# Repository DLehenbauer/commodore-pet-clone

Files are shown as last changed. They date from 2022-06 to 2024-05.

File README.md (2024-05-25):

## PET Clone

Open hardware clone of the Commodore CBM/PET using modern parts.
Some assembly required.  :-)

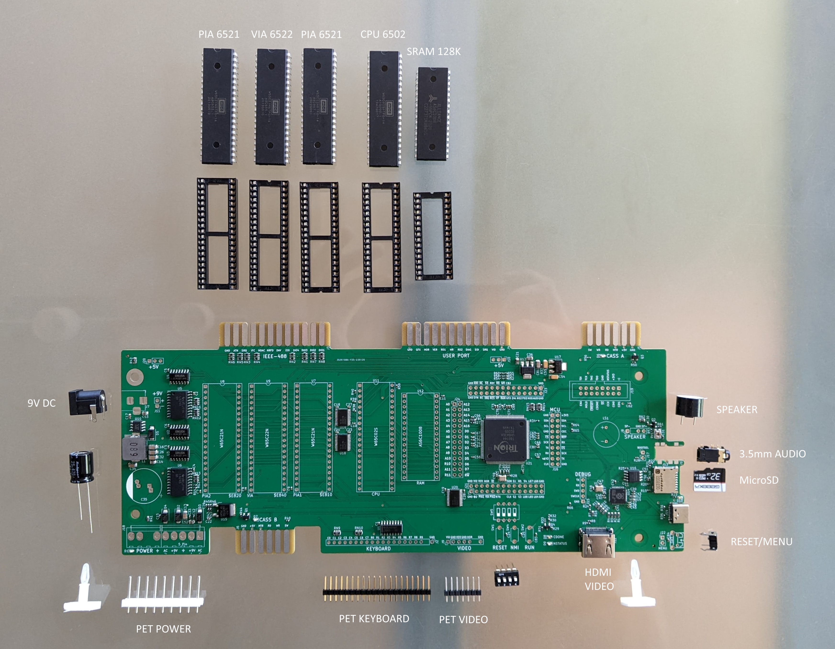
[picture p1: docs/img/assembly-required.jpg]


## Status

Working prototype.  PCB and SMT manufacturing files are [here](https://github.com/DLehenbauer/commodore-pet-clone/tree/main/hw/Mainboard/production).

## About

This open hardware CBM/PET clone can be used in two ways:

1. By itself with an HDMI display and USB keyboard
2. As a mainboard replacement to repair/enhance a vintage CBM/PET

You can also do both at once, as shown in the image below:

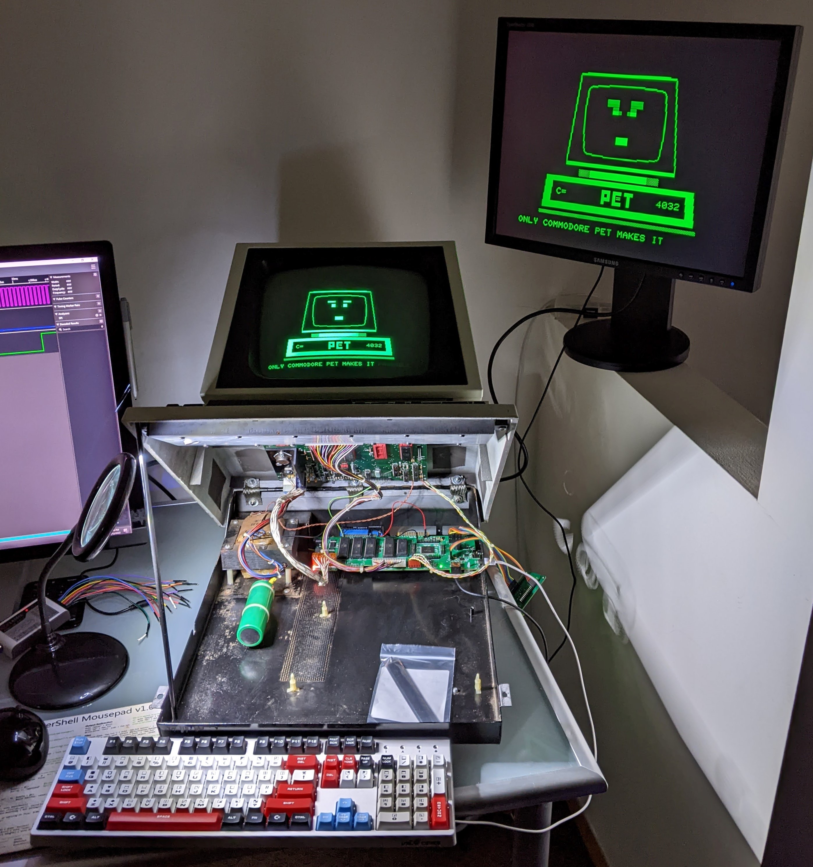
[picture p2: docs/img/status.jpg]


## Design

The following block diagram provides an overview of the system architecture:



Here are the highlights:

* CPU and I/O are similar to the original Commodore design, using the 6502, PIA, and VIA.
* Main RAM, Display RAM and ROM are combined on a single 128K SRAM.
  * On POR the MCU initializes $9000-FFFF with the user's selected ROM set
  * After initialization, $9000-FFFF is write protected.
* Timing, address decoding, and native PET video are consolidated on a small FPGA.
* The MCU reads display RAM and mirrors the PET video to HDMI (via bit-banged DVI)
* The MCU also reports USB keyboard input to the FPGA
  * The FPGA intercepts reads from $E812 to inject USB key input as-needed
  * When no USB keys are pressed, the read passes through to PIA1.

## Contributing

Collaborators warmly appreciated (see [Issues](https://github.com/DLehenbauer/commodore-pet-clone/issues)).

## License

This project is public domain under the CC0-1.0 license, exempting portions incorporated
from other open source projects as noted [here](NOTICE.md) and in the source code.



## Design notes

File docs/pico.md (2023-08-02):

# Pico Debugging

Used ExpressIf directions
[Outdated setup for WSL2](https://github.com/robotdad/piconotes)

Setup:

* Flash Pico with the [Picoprobe UF2 file](https://www.raspberrypi.com/documentation/microcontrollers/raspberry-pi-pico.html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).

## Share Picoprobe with WSL

```sh
usbipd wsl attach --hardware-id 2e8a:0004
```

## Listen to UART

```sh
minicom -b 115200 -o -D /dev/ttyACM0
```

## Specs

* [Device Class Definition for Human Interface Devices (HID)](https://www.usb.org/sites/default/files/hid1_11.pdf)
* [HID Usage Tables](https://usb.org/sites/default/files/hut1_3_0.pdf)
* [Pinout](https://pico.pinout.xyz/)

## CMD

7 | 6 | 5 | 4 | 3 | 2 | 1 | 0
-|-|-|-|-|-|-|-
 LEN[2] | LEN[1] | LEN[0] | x | x | x | RW_B | A16

CMD        |          binary             |      hex
-----------|-----------------------------|-----------------
READ_AT    | { 7'b011_xxx_1, addr[16] }  |
READ_NEXT  | { 8'b001_xxx_1_x            |
WRITE_AT   | { 7'b100_xxx_0, addr[16] }  |

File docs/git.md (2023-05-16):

# Git

## Fix broken submodule

1. Remove from .git/config
2. Remove from .gitmodules

```sh
rm -rf fw/external/no-OS-FatFS-SD-SPI-RPi-Pico
git rm --cached fw/external/no-OS-FatFS-SD-SPI-RPi-Pico
rm -rf .git/modules/fw/external/no-OS-FatFS-SD-SPI-RPi-Pico
```

Alternate:
```sh
git submodule deinit -f ./fw/external/no-OS-FatFS-SD-SPI-RPi-Pico
```

## Setup submodule at tag

```sh
pushd fw/external
git submodule add https://github.com/carlk3/no-OS-FatFS-SD-SPI-RPi-Pico.git
pushd no-OS-FatFS-SD-SPI-RPi-Pico
git fetch --tags
git checkout tags/v1.0.8
popd
git add no-OS-FatFS-SD-SPI-RPi-Pico
git commit -m "Move 'no-OS-FatFS-SD-SPI-RPi-Pico' to tags/v1.0.8"
popd
```

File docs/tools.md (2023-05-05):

# Tools

## PCB Design

* [KiCad](https://www.kicad.org/)
  * [JLC2KiCadLib](https://github.com/TousstNicolas/JLC2KiCad_lib)
  * [KiCAD JLCPCB tools](https://github.com/Bouni/kicad-jlcpcb-tools)
  * [Fabrication Toolkit](https://github.com/bennymeg/JLC-Plugin-for-KiCad)
* [Freerouting](https://github.com/freerouting/freerouting/releases)
  * `winget install -e --id EclipseAdoptium.Temurin.17.JRE`
* [LTSpice](https://www.analog.com/en/design-center/design-tools-and-calculators/ltspice-simulator.html)
  * [Parts](https://www.diyaudio.com/community/threads/a-large-free-ltspice-model-library.360086/)
* Online calculators
  * [VIA Size Calculator](https://j.mp/via-calc)
  * [Resistor Calculator](https://circuitdigest.com/calculators/lm317-resistor-voltage-calculator)
  * [LM317 Calculator](https://circuitdigest.com/calculators/lm317-resistor-voltage-calculator)
  * [Switch Debounce Calculator](https://clisystems.com/tool_debounce.php)
  * [Trace Width Calculator](https://www.digikey.com/en/resources/conversion-calculators/conversion-calculator-pcb-trace-width)
  * [Trace Impedance Calculator](https://www.eeweb.com/tools/edge-coupled-microstrip-impedance/)
* [JLCPCB Capabilities](https://jlcpcb.com/capabilities/Capabilities)
* [JLCPCB Parts Search](https://yaqwsx.github.io/jlcparts/#/)

Property            | Value
--------------------|--------------------------
Thickness           | 1.6 mm
Dielectric constant | 4.5 (double-sided PCB)
Outer copper layer  | 1 oz/ft^2 (35 um)

## FPGA & Verilog

* [Quartus II Web Edition 13.0 SP1](https://fpgasoftware.intel.com/13.0sp1/?edition=web)
* [Icarus Verilog & GTKWave](http://bleyer.org/icarus/)
* [vhd2vl](https://github.com/ldoolitt/vhd2vl)

## Logic Analyzer

* [PulseView](https://www.sigrok.org/wiki/Downloads) for [HiLetgo 8Ch Logic Analyzer](https://www.amazon.com/dp/B077LSG5P2)
  * Install WinUSB driver with [ZaDig](https://zadig.akeo.ie/) for device 0925 3881
* [KingstVIS](http://www.qdkingst.com/en/download) for [LA1010 16Ch Logic Analyzer](https://www.amazon.com/dp/B07D21GG6J)

## Drawing

* [Diagrams.net](https://app.diagrams.net/)
* [WaveDrom](https://wavedrom.com/editor.html)

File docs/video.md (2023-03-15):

# Video

## Non-CRTC Timing

Measurements from a 2001-32N (1979):

Signal | Frequency  | Source
-------|------------|----------
Crystal| 16.007 MHz | I1 pin 1
CPU    | 1.0009 MHz | 6502 pin 37
HSync  | 15.63 KHz  | Video pin 5 (consistent with 16.007 MHz / 1024 = 15.632 KHz)
VSync  | 60.12 Hz   | Video pin 3 (consistent with 15.632 KHz / 260 lines = ~60.122 Hz)

Closest CRTC settings:

Register | Value | Description
---------|-------|-----------------------------------------------
 R0      |   63  | H_TOTAL = 8 MHz pixel clock / 8 pixel char / (64 chars - 1) = 15.625 KHz
 R1      |   40  | H_DISPLAYED = 40 columns
 R2      |   48  | H_SYNC_POS
 R3[3:0] |    1  | H_SYNC_WIDTH = 1
 R3[7:4] |    5  | V_SYNC_WIDTH = 5
 R4      |   32  | V_TOTAL = 15.625 KHz / ((33 rows - 1) * 8 lines per row) = 61.04 Hz
 R5      |    5  | V_LINE_ADJUST = 15.625 KHz / (33 rows * 8 lines per row + 5 lines) = 60.10 Hz
 R6      |   25  | V_DISPLAYED = 25 rows
 R7      |   28  | V_SYNC_POS
 R9      |    7  | SCAN_LINE = 8 pixel character height (-1)

## CRTC Timing

Measurements from 8032 power on:

Signal | Frequency | Duty       | Source
-------|-----------|------------|-----------
HSync  | 20 KHz    | 70-70.126% | Video connector
VSync  | 60.062 Hz | 95.195%    | Video connector

## CRTC Bugs:

Noted problems in my current CRTC implementation:
* Bug in vertical timing: (61 Hz instead of 60 Hz)
* V. Sync width currently fixed at 16 scanlines (per original Motorola chips)

## Tools

* [VGA Timing Calculator](https://www.epanorama.net/faq/vga2rgb/calc.html)
* [Pixel Clock Calculator](https://www.monitortests.com/pixelclock.php)

## Reference

* VGA
  * [VGA Timings](http://martin.hinner.info/vga/timing.html)
  * [TinyVGA Timings](http://www.tinyvga.com/vga-timing)
* DVI
  * [CEA-861-D](https://ia903002.us.archive.org/1/items/CEA-861-D/CEA-861-D.pdf)
* NTSC / PAL
  * [Timing Characteristics](http://www.kolumbus.fi/pami1/video/pal_ntsc.html)
* CRTC
  * [Operation](http://www.6502.org/users/andre/hwinfo/crtc/crtc.html)
  * [Internals](http://www.6502.org/users/andre/hwinfo/crtc/internals/index.html)
  * [Wikipedia](https://en.wikipedia.org/wiki/Motorola_6845)
  * [Register Values](https://github.com/sjgray/cbm-edit-rom/blob/master/docs/CRTC%20Registers.txt)
  * [Reverse Engineering](https://stardot.org.uk/forums/viewtopic.php?t=22008)
  * Datasheet
    * [Rockwell R6545](http://archive.6502.org/datasheets/rockwell_r6545-1_crtc.pdf)
    * [Motorolla MC6845](http://m.www.datasheets.pl/elementy_czynne/IC/MC6845.pdf)
    * [C6845 CRT Controller IP](https://colorcomputerarchive.com/repo/Documents/Datasheets/SY6845E-C6845%20CRT%20Controller%20(CAST).pdf)

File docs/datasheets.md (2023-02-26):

# Datasheets

## 6502 CPU

* [Western Digital W65C02S](https://www.westerndesigncenter.com/wdc/documentation/w65c02s.pdf)

## 6520/6521 PIA

* [Western Digital W65C21](https://www.westerndesigncenter.com/wdc/documentation/w65c21.pdf)
* [Rockwell R6520](http://archive.6502.org/datasheets/rockwell_r6520_pia.pdf)

## 6522 VIA

* [Western Digital W65C22](https://www.westerndesigncenter.com/wdc/documentation/w65c22.pdf)

## 6545 CRTC

* [Rockwell R6545](http://archive.6502.org/datasheets/rockwell_r6545-1_crtc.pdf)

## SRAM

* [AS6C1008-55PCN](https://www.alliancememory.com/wp-content/uploads/pdf/AS6C1008feb2007.pdf)
* [IS61WV1288EEBLL](https://www.issi.com/WW/pdf/61-64WV1288EEBLL.pdf)

## MCU

* [RP2040](https://datasheets.raspberrypi.com/rp2040/rp2040-datasheet.pdf)
* [ARM PrimeCell Synchronous Serial Port (PL022)](https://developer.arm.com/documentation/ddi0194/h/introduction/about-the-arm-primecell-ssp--pl022-)

## Other

* [MC3446](http://pdf.datasheetcatalog.com/datasheets/400/501349_DS.pdf) Original IEEE-488 Bus Transceiver
* [SN74LVC4245A](https://www.ti.com/lit/ds/symlink/sn74lvc4245a.pdf) Octal Bus Transceiver and 3.3-V to 5-V Shifter
* [Card Edge Connector](https://files.edac.net/edac/content/305/305-024-500-501%20-%20EDAC%20Card%20Edge%20Connector.PDF)

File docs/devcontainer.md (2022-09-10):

[Picoprobe UF2 binary download](https://datasheets.raspberrypi.com/soft/picoprobe.uf2)

[Hints from ExpressIf Docs](https://github.com/espressif/vscode-esp-idf-extension/blob/HEAD/docs/tutorial/using-docker-container.md)

Install 'libusb-win32' driver for "Picoprobe (Interface 2)" using [Zadig](http://zadig.akeo.ie).

Install [usbipd](https://github.com/dorssel/usbipd-win/releases) on Windows

Install usbipd in WSL:
```
sudo apt update && \
    apt install linux-tools-5.4.0-77-generic hwdata && \
    update-alternatives --install /usr/local/bin/usbip usbip /usr/lib/linux-tools/5.4.0-77-generic/usbip 20
```

From PowerShell, list devices on Windows:

```
usbipd list wsl
```

Bind 'Picoprobe':

```
usbipd bind --busid 4-2
usbipd wsl attach --busid 4-2
```

Verify attachment from WSL and from container:
```
dmesg | tail
```

Verify that you can connect to the urt with minicom:
```
sudo minicom -D /dev/ttyACM0 -b 115200
```
(If not, you probably forgot to expose the device in the container with '--device=/dev/ttyACM0')

Test that OpenOCD can connect with 'sudo':
```
sudo openocd -f interface/picoprobe.cfg -f target/rp2040.cfg -s tcl
```
(If not, you probably forgot to start the container with --privileged)

TODO: Someday figure out how to connect to Picoprobe as a non-root user:
https://elinux.org/Accessing_Devices_without_Sudo

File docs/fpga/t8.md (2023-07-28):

# T8Q144

## Programming

### Install USB Driver

#### Windows

* Connect board to USB
* Run [Zadig](https://zadig.akeo.ie/) 2.7 or later
* Choose Options > List All Devices
* Select 'Dual RS232-HS'
* Select 'libusb-win32' driver
* Click 'Replace Driver'
* Repeat for 'USB Serial Converter'

## Documentation

Links to frequently referenced [Trion documentation](https://www.efinixinc.com/support/docs.php?p=t) (must [login](https://www.efinixinc.com/support/login.php) to access).

### Design

* [T8 Data Sheet](https://www.efinixinc.com/docs/trion8-ds-v4.5.pdf)
* [Trion Interactive Hardware Design Checklist and Guidelines](https://www.efinixinc.com/support/design-guide.php)
* [Trion Packaging User Guide](https://www.efinixinc.com/docs/trion-packaging-ug-v4.5.pdf)
* [Trion Interfaces User Guide](https://www.efinixinc.com/docs/trion-interfaces-ug-v8.0.pdf)
* [AN 006: Configuring Trion FPGAs](https://www.efinixinc.com/docs/an006-configuring-trion-fpgas-v5.4.pdf)
* [AN 038: Programming with MCU and JTAG](https://www.efinixinc.com/docs/an038-programming-with-mcu-and-jtag-v1.0.pdf)
* Reference implementations:
  * [FireAnt T8F81 Dev Board](https://github.com/jungle-elec/FireAnt/blob/master/FireAnt_Schematic.pdf)
  * [Xyloni T8F81 Dev Board](https://github.com/Efinix-Inc/xyloni/blob/master/docs/Schematic%20Prints.PDF)
  * [T8F81 Dev Board](https://www.efinixinc.com/docs/t8f81-dev-board-schematics-v1.1.pdf)
  * [T20BGA256 Dev Board](https://www.efinixinc.com/docs/t20bga256-dev-board-schematics-v3.0.pdf)
  * [PiStorm32 Lite](https://github.com/PiStorm/pistorm32-lite-hardware/blob/main/PDF/ps32_lite_rev_a_public_schematic.pdf)

### Efinity Software

* [Timing Closure](https://www.efinixinc.com/docs/efinity-timing-closure-v3.0.pdf)

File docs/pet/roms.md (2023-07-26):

# Roms

## Disassembled Roms

* [Basic and Kernal](http://www.zimmers.net/anonftp/pub/cbm/src/pet/pet_rom4_disassembly.txt)
* [Editor](http://www.zimmers.net/anonftp/pub/cbm/firmware/computers/pet/edit-4-40-n-60hz-901499-01.dis.txt)

## Reference

* [ROM Hash Codes](http://mhv.bplaced.net/cbmroms/cbmroms.php)
* [ROM Genealogy](http://penguincentral.com/retrocomputing/PET/petroms.pdf)

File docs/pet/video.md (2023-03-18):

# Video

## Non-CRTC Timing

Measurements from a 2001-32N (1979):

Signal | Frequency  | Source
-------|------------|----------
Crystal| 16.007 MHz | I1 pin 1
CPU    | 1.0009 MHz | 6502 pin 37
HSync  | 15.63 KHz  | Video pin 5 (consistent with 16.007 MHz / 1024 = 15.632 KHz)
VSync  | 60.12 Hz   | Video pin 3 (consistent with 15.632 KHz / 260 lines = ~60.122 Hz)

Closest CRTC settings:

Register | Value | Description
---------|-------|-----------------------------------------------
 R0      |   63  | H_TOTAL = 8 MHz pixel clock / 8 pixel char / (64 chars - 1) = 15.625 KHz
 R1      |   40  | H_DISPLAYED = 40 columns
 R2      |   48  | H_SYNC_POS
 R3[3:0] |    1  | H_SYNC_WIDTH = 1
 R3[7:4] |    5  | V_SYNC_WIDTH = 5
 R4      |   32  | V_TOTAL = 15.625 KHz / ((33 rows - 1) * 8 lines per row) = 61.04 Hz
 R5      |    5  | V_LINE_ADJUST = 15.625 KHz / (33 rows * 8 lines per row + 5 lines) = 60.10 Hz
 R6      |   25  | V_DISPLAYED = 25 rows
 R7      |   28  | V_SYNC_POS
 R9      |    7  | SCAN_LINE = 8 pixel character height (-1)

## CRTC Timing

Measurements from 8032 power on:

Signal | Frequency | Duty       | Source
-------|-----------|------------|-----------
HSync  | 20 KHz    | 70-70.126% | Video connector
VSync  | 60.062 Hz | 95.195%    | Video connector

## Tools

* [VGA Timing Calculator](https://www.epanorama.net/faq/vga2rgb/calc.html)
* [Pixel Clock Calculator](https://www.monitortests.com/pixelclock.php)

## Reference

* VGA
  * [VGA Timings](http://martin.hinner.info/vga/timing.html)
  * [TinyVGA Timings](http://www.tinyvga.com/vga-timing)
* DVI
  * [CEA-861-D](https://ia903002.us.archive.org/1/items/CEA-861-D/CEA-861-D.pdf)
* NTSC / PAL
  * [Timing Characteristics](http://www.kolumbus.fi/pami1/video/pal_ntsc.html)
* CRTC
  * [Operation](http://www.6502.org/users/andre/hwinfo/crtc/crtc.html)
  * [Internals](http://www.6502.org/users/andre/hwinfo/crtc/internals/index.html)
  * [Wikipedia](https://en.wikipedia.org/wiki/Motorola_6845)
  * [Register Values](https://github.com/sjgray/cbm-edit-rom/blob/master/docs/CRTC%20Registers.txt)
  * [Reverse Engineering](https://stardot.org.uk/forums/viewtopic.php?t=22008)
  * Datasheet
    * [Motorolla MC6845](https://archive.org/details/bitsavers_motorolada_1431515/page/n9/mode/2up)
    * [Motorolla AN-851](https://archive.org/details/bitsavers_motorolaapaMC6845CRTCSimplifiesVideoDisplayControl_9722748/mode/2up)
    * [Rockwell R6545](http://archive.6502.org/datasheets/rockwell_r6545-1_crtc.pdf)
    * [C6845 CRT Controller IP](https://colorcomputerarchive.com/repo/Documents/Datasheets/SY6845E-C6845%20CRT%20Controller%20(CAST).pdf)
    * [DB6845 CRTC IP](https://www.digitalblocks.com/files/DB6845-DS-V1_1.pdf)

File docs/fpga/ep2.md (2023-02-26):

# EP2

## Resources

* [Quartus II TimeQuest Timing Analyzer Cookbook](https://embedders.org/system/files/mnl_timequest_cookbook.pdf)
* [TimeQuest User Guide](https://www.intel.com/content/dam/support/us/en/programmable/support-resources/fpga-wiki/asset02/timequest-user-guide.pdf)

## Clock In

Pin | Fn
-|-
17|50 MHz source
18|
21|
22|
88|
89|
90|
91|

## Clock Out

Pin | Pn
-|-
31|PLL1_OUTp
32|PLL1_OUTn
103|PLL2_OUTp
104|PLL2_OUTn

## Reserved

[EP2C5 Mini Dev Board](http://land-boards.com/blwiki/index.php?title=Cyclone_II_EP2C5_Mini_Dev_Board#I.2FO_Pin_Mapping)

Pin | Function | Notes
-|-|-
3 | LED D2 | Drive pin low to light LED.
7 | LED D4 | Drive pin low to light LED.
9 | LED D5 | Drive pin low to light LED.
17 | 50 MHz | Clock input from onboard oscillator.
26 | 1V2 | VCC 1.2V for EP2C8.  (See note below)
27 | GND | GND for EP2C8.  (See note below)
73 | POR | Power on reset. (10uF / 10K RC delay)
80 | GND | GND for EP2C8.  (See note below)
81 | 1V2 | VCC 1.2V for EP2C8.  (See note below)
144 | KEY | Pin low when button pressed.  Requires FPGA internal pull up.

**Note:** On EP2C5 boards pins 26, 27, 80, 81 can be used as normal if the "zero ohm" resistors are removed.

## SPI

Signal | GPIO | Pin # | Label |  FPGA
-------|------|-------|-------|--------
CE1    |   7  |   26  |   A2  | PIN_67
CN_N   |   8  |   24  |   A3  | PIN_64
TX     |   9  |   21  |   A4  | PIN_60
RX     |  10  |   19  |   A5  | PIN_58
SCLK   |  11  |   23  |   A6  | PIN_55

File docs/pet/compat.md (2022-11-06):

# Compatibility Notes

## NPA Demo

```text
(C:$e0c1) load "d:\pet\npa.prg" 0
Loading d:\pet\npa.prg from 0401 to 7E94 (7A94 bytes)
```

### Uses VRAM mirroring to detect 40 vs. 80 columns

```text
.C:0517  A9 21       LDA #$21
.C:0519  8D 00 84    STA $8400
.C:051c  A9 20       LDA #$20
.C:051e  8D 00 80    STA $8000
.C:0521  AD 00 84    LDA $8400
.C:0524  C9 21       CMP #$21
.C:0526  F0 59       BEQ $0581  ; Quit if $8000 does not overwrite $8400
```

### Uses timing to detect 50 vs. 60 Hz

```text
.C:055e  AC 44 E8    LDY $E844
.C:0561  AE 45 E8    LDX $E845
.C:0564  AD D7 05    LDA $05D7
.C:0567  C9 B7       CMP #$B7
.C:0569  B0 01       BCS $056C  ; Quit
.C:056b  60          RTS
```

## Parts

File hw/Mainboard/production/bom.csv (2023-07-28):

Designator | Footprint | Quantity | Value | LCSC Part #
C1, C10, C11, C13, C18, C19, C2, C20, C22, C23, C26, C27, C28, C3, C30, C34, C39, C4, C40, C41, C42, C43, C44, C45, C46, C49, C5, C51, C6, C61, C63, C64, C66, C68, C7, C71, C72, C74, C76, C77, C78, C79, C8, C80, C85, C86, C9 | C_0402_1005Metric | 47 | 100n | C307331
C12, C15, C33, C59 | C_0402_1005Metric | 4 | 22n | C1532
C14, C29, C31, C32, C53, C60, C75, C83 | C_0402_1005Metric | 8 | 1u | C52923
C16, C17, C24, C25, C70, C81, C82 | C_0603_1608Metric | 7 | 10u | C96446
C21, C36 | C_0805_2012Metric | 2 | 22u | C45783
C35 | CP_Radial_D18.0mm_P5.00mm_P7.50mm | 1 | 470u | 35YXJ470M10X16
C37, C38, C52 | C_0402_1005Metric | 3 | 2.2u 6.3V | C12530
C47, C48 | C_0402_1005Metric | 2 | 30p | C1570
C50 | C_0402_1005Metric | 1 | 10u 6.3V | C15525
C54 | C_1206_3216Metric | 1 | 47u 10V | C96123
C55 | C_0603_1608Metric | 1 | 47n | C1622
C58 | C_0402_1005Metric | 1 | 4.7u 10V | C23733
C62, C65, C67, C69, C73 | C_0402_1005Metric | 5 | 10n | C15195
C84 | C_0603_1608Metric | 1 | 4.7u 16V | C19666
D1, D6, D7, D9 | LED_0603_1608Metric | 4 | LED_RED | C2286
D10, D8 | LED_0603_1608Metric | 2 | LED_GRN | C72043
D11, D12, D13, D14, D5 | D_SOD-123F | 5 | SM4007 | C64898
D2, D3, D4 | D_SMA | 3 | SS34 | C8678
FB1 | L_0603_1608Metric | 1 | 600 200ma | C1002
H1 | MountingHole_4mm_Pad | 1 | MountingHole_Pad
H2, H3, H4 | PET_MountingHole_4mm | 3 | MountingHole
HS1 | V1100SMDBL | 1 | Heatsink_Pad
J1 | CUI_SJ-43504-SMT-TR | 1 | SJ-43504-SMT-TR
J10, J20 | PinHeader_2x03_P2.54mm_Vertical | 2 | 5V PWR
J11 | PinHeader_1x02_P2.54mm_Vertical | 1 | 9V POWER
J12 | HDMI_A_Molex_208658-1001_Horizontal | 1 | NOT_HDMI_A | C138388
J13 | TF-SMD_TF-PUSH | 1 | MicroSD | C393941
J14 | USB-C_SMD-TYPE-C-31-M-12 | 1 | USB2.0_HOST_TYPE_C | C165948
J15 | PinHeader_2x08_P2.54mm_Vertical | 1 | KEYBOARD_EX
J16 | PinHeader_2x11_P2.54mm_Vertical | 1 | MCU
J18 | PET_POWER_Molex_KK-396_A-41791-0009_1x09_P3.96mm_Vertical | 1 | PET POWER
J19 | IDC-Header_2x08_P2.54mm_Vertical | 1 | PROG
J2 | CBM_PET_KEYBOARD_KEYED_20P | 1 | KEYBOARD | 2-826646-0
J21 | PinHeader_2x14_P2.54mm_Vertical | 1 | FPGA-P4 | 929975-01-14
J22 | PinHeader_1x02_P2.54mm_Vertical | 1 | MENU
J23 | PinHeader_2x14_P2.54mm_Vertical | 1 | FPGA_P2 | 929975-01-14
J24 | PinHeader_2x15_P2.54mm_Vertical | 1 | Conn_02x15_Odd_Even
J25 | PinHeader_2x09_P2.54mm_Vertical | 1 | IEEE_HEADER
J26 | PinHeader_2x11_P2.54mm_Vertical | 1 | USER_HEADER
J27 | PinHeader_1x06_P2.54mm_Vertical | 1 | CASS_A_HEADER
J28 | PinHeader_1x06_P2.54mm_Vertical | 1 | CASS_B_HEADER
J3 | CBM_PET_IEEE_EDGE_CON_24P | 1 | IEEE
J4 | CBM_PET_USER_EDGE_CON_24P | 1 | USER
J5 | CBM_PET_CASS_EDGE_CON_12P | 1 | CASS A
J6 | CBM_PET_CASS_EDGE_CON_12P | 1 | CASS B
J7 | BarrelJack_Horizontal | 1 | 9V POWER | CON-SOCJ-2155
J8 | PinHeader_1x02_P2.54mm_Vertical | 1 | FLASH
J9 | PET_Video | 1 | VIDEO
JP1 | SolderJumper-3_P1.3mm_Open_RoundedPad1.0x1.5mm | 1 | CASS A ~{SWITCH}
JP10 | SolderJumper-3_P1.3mm_Open_RoundedPad1.0x1.5mm | 1 | VIDEO_OR_5V
JP2 | SolderJumper-3_P1.3mm_Open_RoundedPad1.0x1.5mm | 1 | CASS B ~{SWITCH}
JP3 | SolderJumper-3_P1.3mm_Open_RoundedPad1.0x1.5mm | 1 | CASS A READ
JP4 | SolderJumper-3_P1.3mm_Open_RoundedPad1.0x1.5mm | 1 | CASS B READ
JP5 | SolderJumper-3_P1.3mm_Open_RoundedPad1.0x1.5mm | 1 | CASS A ~{MOTOR}
JP6 | SolderJumper-3_P1.3mm_Open_RoundedPad1.0x1.5mm | 1 | CASS B ~{MOTOR}
JP7 | SolderJumper-2_P1.3mm_Open_RoundedPad1.0x1.5mm | 1 | DVI_CEC
JP8 | SolderJumper-3_P1.3mm_Open_RoundedPad1.0x1.5mm | 1 | DVI_SDA
JP9 | SolderJumper-3_P1.3mm_Open_RoundedPad1.0x1.5mm | 1 | DVI_SCL
LS1 | AT1220TT9R | 1 | Speaker
PT1, PT10, PT11, PT12, PT13, PT14, PT15, PT16, PT17, PT18, PT19, PT2, PT20, PT21, PT22, PT23, PT24, PT25, PT26, PT27, PT28, PT29, PT30, PT31, PT32, PT33, PT35, PT36, PT37, PT38, PT39, PT4, PT5, PT55, PT56, PT6, PT7, PT8, PT9 | NetTie-2_SMD_Pad_1.6_to_0.4mm | 39 | PowerTie_2
PT40, PT41, PT42, PT43, PT44, PT45, PT46, PT47, PT48, PT49, PT50, PT51, PT52, PT53, PT54 | NetTie-2_SMD_Pad_0.28 | 15 | PowerTie_2
Q1, Q3 | SOT-23_L2.9-W1.3-P1.90-LS2.4-BR | 2 | AO3401A | C15127
Q4 | SOT-23 | 1 | MMBT3904 | C20526
R1, R10, R11, R16, R2, R3, R4, R5, R6 | R_0603_1608Metric | 9 | 270 | C22966
R12, R15 | R_0603_1608Metric | 2 | 27 | C25190
R13, R14 | R_0402_1005Metric | 2 | 470 | C25117
R17, R23, R26, R29, R31, R66 | R_0402_1005Metric | 6 | 1k | C11702
R18, R20, R25, R27, R49, R52, R55, R56, R57 | R_0402_1005Metric | 9 | 10k | C25744
R19, R21, R22, R48, R51, R63, R67, R68, R69, R70, R71 | R_0402_1005Metric | 11 | 33 | C25105
R24 | R_0402_1005Metric | 1 | 15k | C25756
R28, R47 | R_0402_1005Metric | 2 | 300 | C25102
R30, R33 | R_0402_1005Metric | 2 | 100k | C25741
R32 | R_0402_1005Metric | 1 | 1.2k | C25862
R34 | R_0402_1005Metric | 1 | 12k 1% | C25752
R35, R36 | R_0402_1005Metric | 2 | 56k | C25796
R37 | R_0402_1005Metric | 1 | 3.9k | C51721
R38, R39, R40, R59 | R_0402_1005Metric | 4 | 4k7 | C25900
R41, R44, R50 | R_0402_1005Metric | 3 | 1k5 | C25867
R42 | R_0805_2012Metric | 1 | 68 | C17802
R43 | R_0402_1005Metric | 1 | 120 | C25079
R45 | R_0402_1005Metric | 1 | 1.5k | C25867
R46 | R_0402_1005Metric | 1 | 5.1k | C25905
R53 | R_0805_2012Metric_Pad1.20x1.40mm_HandSolder | 1 | 4k7 | C17673
R54, R58, R60 | R_0402_1005Metric | 3 | 5.6k | C25908
R61 | R_0805_2012Metric_Pad1.20x1.40mm_HandSolder | 1 | 10 | C17415
R64, R65, R7, R73, R74, R8, R9 | R_0402_1005Metric | 7 | 2k2 | C25879
R72 | R_0805_2012Metric_Pad1.20x1.40mm_HandSolder | 1 | 12k | C17444
RN1, RN3, RN5, RN7 | R_Array_Convex_4x0603 | 4 | 4.7k | C1980
RN10, RN14, RN15, RN16, RN2, RN4, RN6, RN8, RN9 | R_Array_Convex_4x0603 | 9 | 10k | C29718
RN11, RN12, RN13 | R_Array_Convex_4x0603 | 3 | 470 | C25510
SW1 | SW-TH_L6.0-W3.5-P6.50 | 1 | RESET
SW2 | SW-TH_L6.0-W3.5-P6.50 | 1 | RUN
SW3 | APEM_MJTP1117 | 1 | MENU
SW4 | SW-TH_L6.0-W3.5-P6.50 | 1 | NMI
SW5 | SW_DIP_SPSTx04_Slide_6.7x11.72mm_W7.62mm_P2.54mm_LowProfile | 1 | CONFIG
U1 | SOIC-16_3.9x9.9mm_P1.27mm | 1 | 74LS145 | C60829
U10, U15, U17 | TO-252-2 | 3 | LM317AG-TN3-R | C75510
U11 | DIP-40_W15.24mm_Socket | 1 | W65C02S
U12 | DIP-32_W15.24mm_Socket | 1 | AS6C1008
U13 | SOT-223-3_TabPin2 | 1 | AMS1117-3.3 | C6186
U14 | LQFN-56_L7.0-W7.0-P0.4-EP | 1 | RP2040 | C2040
U16 | SOIC-8_5.23x5.23mm_P1.27mm | 1 | W25Q128JVS | C97521
U18, U19, U20 | TSSOP-24_4.4x7.8mm_P0.65mm | 3 | SN74LVC4245APWR | C7859
U2, U3, U4 | SOIC-14_3.9x8.7mm_P1.27mm | 3 | SN74LS07 | C513513
U21 | QFP50P2200X2200X160-144N | 1 | T8Q144C3 | T8Q144C3
U22 | DIP-8_W7.62mm | 1 | LM386
U5, U6 | SOIC-20W_7.5x12.8mm_P1.27mm | 2 | 74LS245 | C129580
U7, U8 | DIP-40_W15.24mm_Socket | 2 | W65C21N
U9 | DIP-40_W15.24mm_Socket | 1 | W65C22N
Y1 | Crystal_SMD_3225-4Pin_3.2x2.5mm | 1 | 12 MHz | C9002

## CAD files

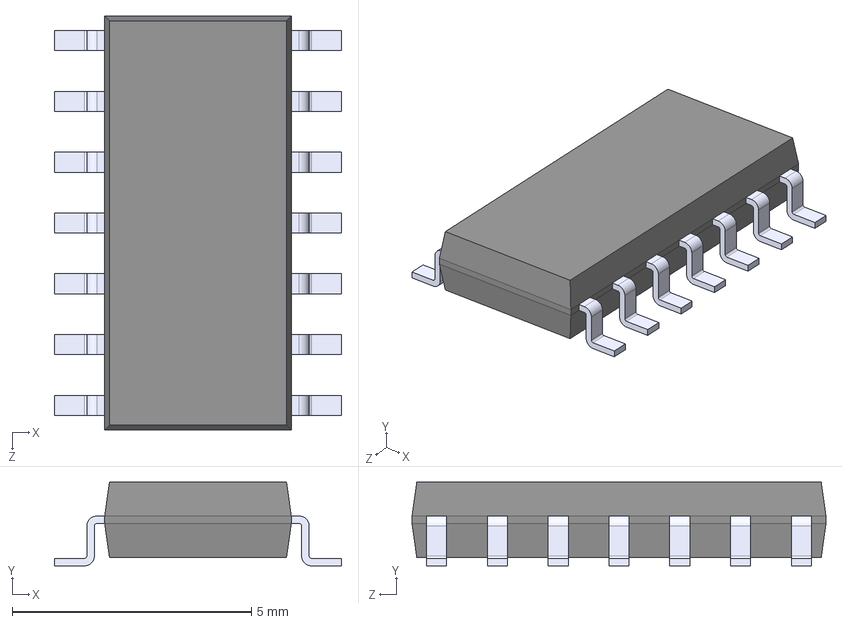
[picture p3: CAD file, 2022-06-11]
hw/Mainboard/SN74LS07DR.step
6.00 x 1.75 x 8.65 mm

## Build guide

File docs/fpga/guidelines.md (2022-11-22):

# SystemVerilog Guidelines

* To aid debugging, use 'casez' rather than 'casex' to avoid swallowing x's caused by uninitialized registers or multiple drivers.

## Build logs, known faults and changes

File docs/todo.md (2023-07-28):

# TODO

* Mfg checklist:
  * ERC
  * Check silkscreen labels
  * DRC / update copper fills
  * Review BOM (esp. look for mixed values)
  * Tag revision in Github
* HW:
  * Clean up SPI:
    * Routing
    * 25k pullups for SD card?
    * Reverse SPI1?  (Recall that SPI is fastest when RP2040 drives clk)
  * Consider FPGA UART
  * Programming
    * Build separate "debug PCB" that integrates:
      * Picoprobe
      * FT2232
      * Moves CDONE/NSTATUS to debug board?
  * Larger net ties for FPGA_*
  * Consider [SMD SRAM](https://jlcpcb.com/partdetail/444095-IS61WV1288EEBLL10TLI/C443418)
  * Align reference designators with original PET?
* Fix signal names:
  * RD/WR_STROBE -> RAM_OE / RAM_WE
  * GRAPHICS vs. gfx
  * CPU signals (cpu_* prefix)
    * RDY vs. cpu_ready
    * SOB vs. /SO vs. so_n
    * BE vs. cpu_en
  * Video signals:
    * vert vs v_sync
    * horiz vs h_sync
* Design
  * Try increasing SPI1 clock rate
  * Try using SPI_SCK as clock instead of oversampling
  * Explore using SPI0 to stream video to MCU in parallel
    * Possibly could bidirectionally send keyboard status at same time
  * Implement 65xx chips on FPGA to make 40-pin chips optional

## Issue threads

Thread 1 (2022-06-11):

Finalizing v0.3 board

DLehenbauer, 2022-06-11:
I'm currently working on finalizing the v0.3 board, which will hopefully become a v1.0 release.

Hardware:
- Cleaning up layout and routing
- Improving silkscreen labeling
- Avoid FPGA pins 80/81 (requires modifying the FPGA dev board)

RTL:
- CRTC emulation
- Video generation

Some future projects:
- Joystick ports
- Integrate / cost-reduce FPGA (possibly Efinix T8Q144)
- Make RPi optional / possibly replace with Pico
- Attempt to shrink board a bit more, while maintaining PET compatible footprint

Collaborators warmly appreciated. :-)

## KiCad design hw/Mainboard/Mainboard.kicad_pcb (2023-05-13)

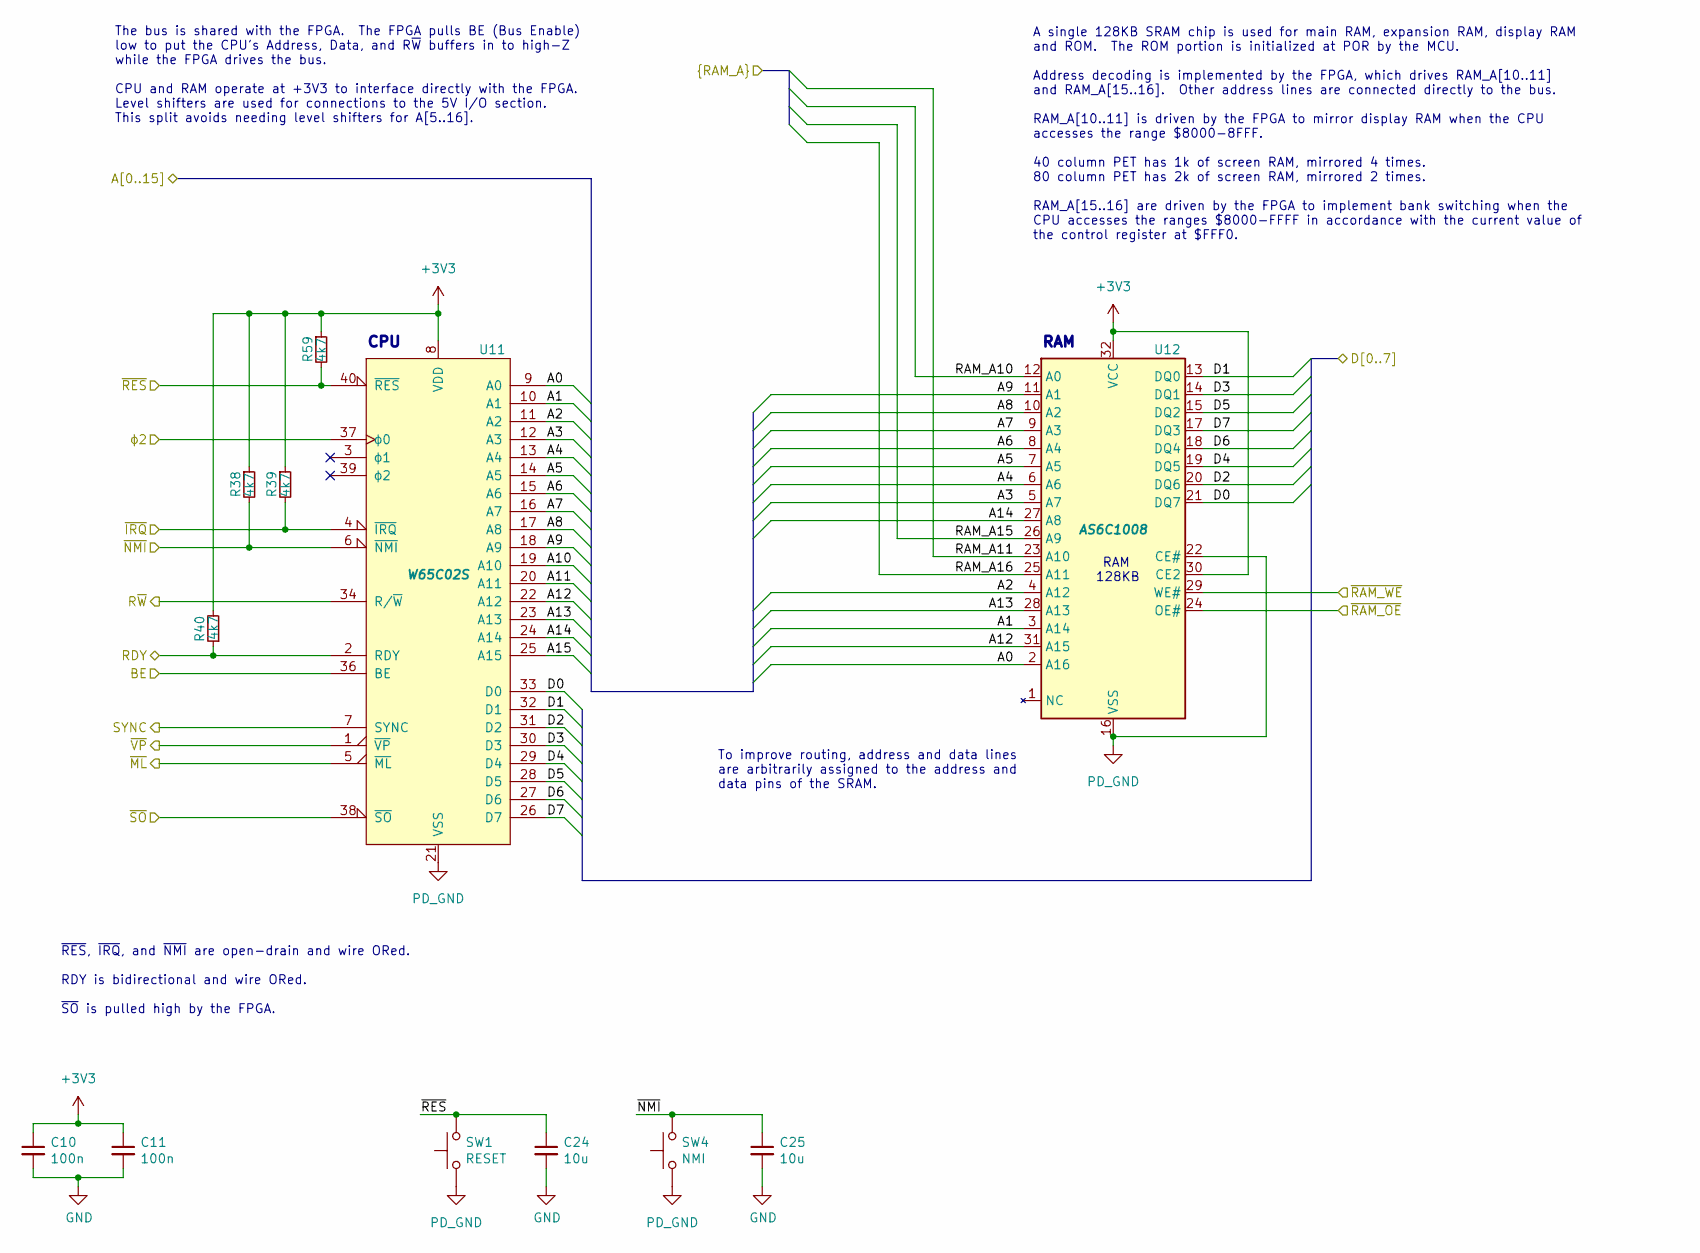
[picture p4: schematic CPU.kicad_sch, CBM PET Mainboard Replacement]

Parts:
C10, C11: 100n; C_0402_1005Metric; LCSC C1525
C24, C25: 10u; C_0603_1608Metric; LCSC C96446
R38, R39, R40, R59: 4k7; R_0402_1005Metric; LCSC C25900
SW1: RESET; SW-TH_L6.0-W3.5-P6.50
SW4: NMI; SW-TH_L6.0-W3.5-P6.50
U11: W65C02S; DIP-40_W15.24mm_Socket; MOUSER 955-W65C02S6TPG-14
U12: AS6C1008; DIP-32_W15.24mm_Socket; MOUSER 913-AS6C1008-55PCN

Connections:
+3V3: C10.1, C11.1, R38.1, R39.1, R40.2, R59.1, U11.8 (VDD), U12.30 (CE2), U12.32 (VCC); also elsewhere on the board
/CPU \ RAM/A0: U11.9 (A0), U12.2 (A16); also elsewhere on the board
/CPU \ RAM/A1: U11.10 (A1), U12.3 (A14); also elsewhere on the board
/CPU \ RAM/A2: U11.11 (A2), U12.4 (A12); also elsewhere on the board
/CPU \ RAM/A3: U11.12 (A3), U12.5 (A7); also elsewhere on the board
/CPU \ RAM/A4: U11.13 (A4), U12.6 (A6); also elsewhere on the board
/CPU \ RAM/A5: U11.14 (A5), U12.7 (A5); also elsewhere on the board
/CPU \ RAM/A6: U11.15 (A6), U12.8 (A4); also elsewhere on the board
/CPU \ RAM/A7: U11.16 (A7), U12.9 (A3); also elsewhere on the board
/CPU \ RAM/A8: U11.17 (A8), U12.10 (A2); also elsewhere on the board
/CPU \ RAM/A9: U11.18 (A9), U12.11 (A1); also elsewhere on the board
/CPU \ RAM/A10: U11.19 (A10); also elsewhere on the board
/CPU \ RAM/A11: U11.20 (A11); also elsewhere on the board
/CPU \ RAM/A12: U11.22 (A12), U12.31 (A15); also elsewhere on the board
/CPU \ RAM/A13: U11.23 (A13), U12.28 (A13); also elsewhere on the board
/CPU \ RAM/A14: U11.24 (A14), U12.27 (A8); also elsewhere on the board
/CPU \ RAM/A15: U11.25 (A15); also elsewhere on the board
/CPU \ RAM/D0: U11.33 (D0), U12.21 (DQ7); also elsewhere on the board
/CPU \ RAM/D1: U11.32 (D1), U12.13 (DQ0); also elsewhere on the board
/CPU \ RAM/D2: U11.31 (D2), U12.20 (DQ6); also elsewhere on the board
/CPU \ RAM/D3: U11.30 (D3), U12.14 (DQ1); also elsewhere on the board
/CPU \ RAM/D4: U11.29 (D4), U12.19 (DQ5); also elsewhere on the board
/CPU \ RAM/D5: U11.28 (D5), U12.15 (DQ2); also elsewhere on the board
/CPU \ RAM/D6: U11.27 (D6), U12.18 (DQ4); also elsewhere on the board
/CPU \ RAM/D7: U11.26 (D7), U12.17 (DQ3); also elsewhere on the board
/CPU \ RAM/RAM_A10: U12.12 (A0); also elsewhere on the board
/CPU \ RAM/RAM_A11: U12.23 (A10); also elsewhere on the board
/CPU \ RAM/RAM_A15: U12.26 (A9); also elsewhere on the board
/CPU \ RAM/RAM_A16: U12.25 (A11); also elsewhere on the board
/CPU \ RAM/~NMI: C25.1, R38.2, SW4.2, U11.6 (~NMI); also elsewhere on the board
/CPU \ RAM/~RES: C24.1, R59.2, SW1.2, U11.40 (~RES); also elsewhere on the board
/MAGIC/FPGA/BE: U11.36 (BE); also elsewhere on the board
/MAGIC/FPGA/RDY: R40.1, U11.2 (RDY); also elsewhere on the board
/MAGIC/FPGA/SYNC: U11.7 (SYNC); also elsewhere on the board
/MAGIC/FPGA/~IRQ: R39.2, U11.4 (~IRQ); also elsewhere on the board
/MAGIC/FPGA/~ML: U11.5 (~ML); also elsewhere on the board
/MAGIC/FPGA/~RAM_OE: U12.24 (OE#); also elsewhere on the board
/MAGIC/FPGA/~RAM_WE: U12.29 (WE#); also elsewhere on the board
/MAGIC/FPGA/~SO: U11.38 (~SO); also elsewhere on the board
/MAGIC/FPGA/~VP: U11.1 (~VP); also elsewhere on the board
/MAGIC/R~W: U11.34 (R/~W); also elsewhere on the board
/MAGIC/ϕ2: U11.37 (ϕ0); also elsewhere on the board
GND: C10.2, C11.2, C24.2, C25.2; also elsewhere on the board
PD_GND: SW1.1, SW4.1, U11.21 (VSS), U12.16 (VSS), U12.22 (CE#); also elsewhere on the board

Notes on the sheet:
RAM
A single 128KB SRAM chip is used for main RAM, expansion RAM, display RAM and ROM. The ROM portion is initialized at POR by the MCU. Address decoding is implemented by the FPGA, which drives RAM_A[10..11] and RAM_A[15..16]. Other address lines are connected directly to the bus. RAM_A[10..11] is dri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
To improve routing, address and data lines are arbitrarily assigned to the address and data pins of the SRAM.
~{RES}, ~{IRQ}, and ~{NMI} are open-drain and wire ORed. RDY is bidirectional and wire ORed. ~{SO} is pulled high by the FPGA.
RAM 128KB
CPU
The bus is shared with the FPGA. The FPGA pulls BE (Bus Enable) low to put the CPU's Address, Data, and R~{W} buffers in to high-Z while the FPGA drives the bus. CPU and RAM operate at +3V3 to interface directly with the FPGA. Level shifters are used for connections to the 5V I/O section. This spli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

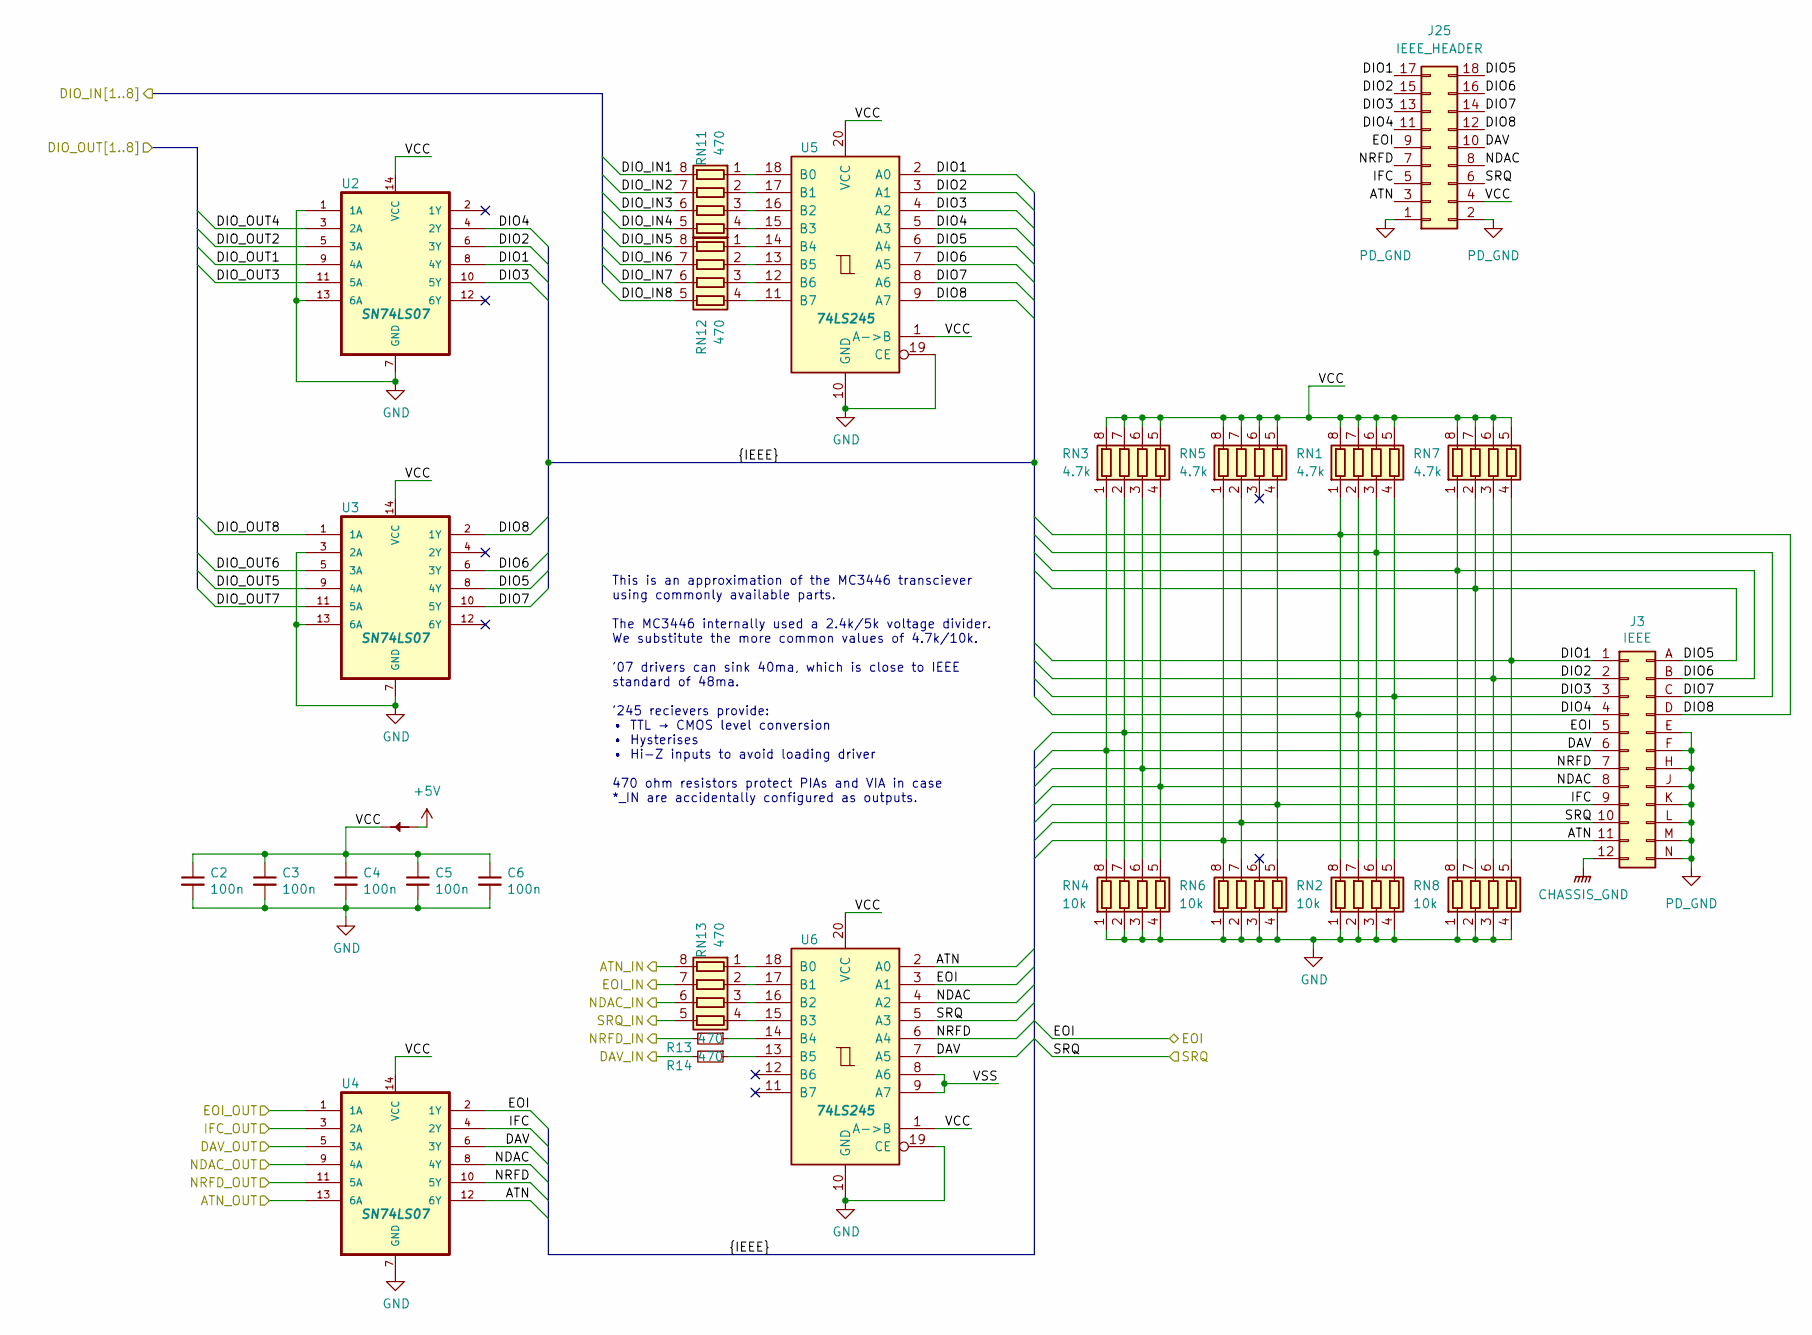
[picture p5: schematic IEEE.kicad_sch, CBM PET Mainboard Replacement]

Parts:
C2, C3, C4, C5, C6: 100n; C_0402_1005Metric; LCSC C1525
J3: IEEE; CBM_PET_IEEE_EDGE_CON_24P
J25: IEEE_HEADER; PinHeader_2x09_P2.54mm_Vertical
PT5: PowerTie_2; NetTie-2_SMD_Pad_1.6_to_0.4mm
R13, R14: 470; R_0402_1005Metric; LCSC C25117
RN1, RN3, RN5, RN7: 4.7k; R_Array_Convex_4x0603; LCSC C1980
RN2, RN4, RN6, RN8: 10k; R_Array_Convex_4x0603; LCSC C29718
RN11, RN12, RN13: 470; R_Array_Convex_4x0603; LCSC C25510
U2, U3, U4: SN74LS07; SOIC-14_3.9x8.7mm_P1.27mm; LCSC C513513
U5, U6: 74LS245; SOIC-20W_7.5x12.8mm_P1.27mm; LCSC C129580

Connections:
+5V: PT5.1; also elsewhere on the board
/IEEE/ATN: J3.11 (ATN), J25.3, RN5.1 (R1.1), RN6.8 (R1.2), U4.12 (6Y), U6.2 (A0)
/IEEE/ATN_IN: RN13.8 (R1.2); also elsewhere on the board
/IEEE/ATN_OUT: U4.13 (6A); also elsewhere on the board
/IEEE/DAV: J3.6 (DAV), J25.10, RN3.1 (R1.1), RN4.8 (R1.2), U4.6 (3Y), U6.7 (A5)
/IEEE/DAV_IN: R14.2; also elsewhere on the board
/IEEE/DAV_OUT: U4.5 (3A); also elsewhere on the board
/IEEE/DIO1: J3.1 (DIO1), J25.17, RN7.4 (R4.1), RN8.5 (R4.2), U2.8 (4Y), U5.2 (A0)
/IEEE/DIO2: J3.2 (DIO2), J25.15, RN7.3 (R3.1), RN8.6 (R3.2), U2.6 (3Y), U5.3 (A1)
/IEEE/DIO3: J3.3 (DIO3), J25.13, RN1.4 (R4.1), RN2.5 (R4.2), U2.10 (5Y), U5.4 (A2)
/IEEE/DIO4: J3.4 (DIO4), J25.11, RN1.2 (R2.1), RN2.7 (R2.2), U2.4 (2Y), U5.5 (A3)
/IEEE/DIO5: J3.A (DIO5), J25.18, RN7.2 (R2.1), RN8.7 (R2.2), U3.8 (4Y), U5.6 (A4)
/IEEE/DIO6: J3.B (DIO6), J25.16, RN7.1 (R1.1), RN8.8 (R1.2), U3.6 (3Y), U5.7 (A5)
/IEEE/DIO7: J3.C (DIO7), J25.14, RN1.3 (R3.1), RN2.6 (R3.2), U3.10 (5Y), U5.8 (A6)
/IEEE/DIO8: J3.D (DIO8), J25.12, RN1.1 (R1.1), RN2.8 (R1.2), U3.2 (1Y), U5.9 (A7)
/IEEE/DIO_IN1: RN11.8 (R1.2); also elsewhere on the board
/IEEE/DIO_IN2: RN11.7 (R2.2); also elsewhere on the board
/IEEE/DIO_IN3: RN11.6 (R3.2); also elsewhere on the board
/IEEE/DIO_IN4: RN11.5 (R4.2); also elsewhere on the board
/IEEE/DIO_IN5: RN12.8 (R1.2); also elsewhere on the board
/IEEE/DIO_IN6: RN12.7 (R2.2); also elsewhere on the board
/IEEE/DIO_IN7: RN12.6 (R3.2); also elsewhere on the board
/IEEE/DIO_IN8: RN12.5 (R4.2); also elsewhere on the board
/IEEE/DIO_OUT1: U2.9 (4A); also elsewhere on the board
/IEEE/DIO_OUT2: U2.5 (3A); also elsewhere on the board
/IEEE/DIO_OUT3: U2.11 (5A); also elsewhere on the board
/IEEE/DIO_OUT4: U2.3 (2A); also elsewhere on the board
/IEEE/DIO_OUT5: U3.9 (4A); also elsewhere on the board
/IEEE/DIO_OUT6: U3.5 (3A); also elsewhere on the board
/IEEE/DIO_OUT7: U3.11 (5A); also elsewhere on the board
/IEEE/DIO_OUT8: U3.1 (1A); also elsewhere on the board
/IEEE/EOI: J3.5 (EOI), J25.9, RN3.2 (R2.1), RN4.7 (R2.2), U4.2 (1Y), U6.3 (A1); also elsewhere on the board
/IEEE/EOI_IN: RN13.7 (R2.2); also elsewhere on the board
/IEEE/EOI_OUT: U4.1 (1A); also elsewhere on the board
/IEEE/IFC: J3.9 (IFC), J25.5, RN5.4 (R4.1), RN6.5 (R4.2), U4.4 (2Y)
/IEEE/IFC_OUT: U4.3 (2A); also elsewhere on the board
/IEEE/NDAC: J3.8 (NDAC), J25.8, RN3.4 (R4.1), RN4.5 (R4.2), U4.8 (4Y), U6.4 (A2)
/IEEE/NDAC_IN: RN13.6 (R3.2); also elsewhere on the board
/IEEE/NDAC_OUT: U4.9 (4A); also elsewhere on the board
/IEEE/NRFD: J3.7 (NRFD), J25.7, RN3.3 (R3.1), RN4.6 (R3.2), U4.10 (5Y), U6.6 (A4)
/IEEE/NRFD_IN: R13.2; also elsewhere on the board
/IEEE/NRFD_OUT: U4.11 (5A); also elsewhere on the board
/IEEE/SRQ: J3.10 (SRQ), J25.6, RN5.2 (R2.1), RN6.7 (R2.2), U6.5 (A3); also elsewhere on the board
/IEEE/SRQ_IN: RN13.5 (R4.2); also elsewhere on the board
/IEEE/VCC: C2.1, C3.1, C4.1, C5.1, C6.1, J25.4, PT5.2, RN1.5 (R4.2), RN1.6 (R3.2), RN1.7 (R2.2), RN1.8 (R1.2), RN3.5 (R4.2), RN3.6 (R3.2), RN3.7 (R2.2), RN3.8 (R1.2), RN5.5 (R4.2), RN5.6 (R3.2), RN5.7 (R2.2), RN5.8 (R1.2), RN7.5 (R4.2), RN7.6 (R3.2), RN7.7 (R2.2), RN7.8 (R1.2), U2.14 (VCC), U3.14 (VCC), U4.14 (VCC), U5.1 (A->B), U5.20 (VCC), U6.1 (A->B), U6.20 (VCC)
/IEEE/VSS: U6.8 (A6), U6.9 (A7)
CHASSIS_GND: J3.12 (GND); also elsewhere on the board
GND: C2.2, C3.2, C4.2, C5.2, C6.2, RN2.1 (R1.1), RN2.2 (R2.1), RN2.3 (R3.1), RN2.4 (R4.1), RN4.1 (R1.1), RN4.2 (R2.1), RN4.3 (R3.1), RN4.4 (R4.1), RN6.1 (R1.1), RN6.2 (R2.1), RN6.3 (R3.1), RN6.4 (R4.1), RN8.1 (R1.1), RN8.2 (R2.1), RN8.3 (R3.1), RN8.4 (R4.1), U2.1 (1A), U2.7 (GND), U2.13 (6A), U3.3 (2A), U3.7 (GND), U3.13 (6A), U4.7 (GND), U5.10 (GND), U5.19 (CE), U6.10 (GND), U6.19 (CE); also elsewhere on the board
unnamed: R13.1, U6.14 (B4)
unnamed: R14.1, U6.13 (B5)
unnamed: RN11.1 (R1.1), U5.18 (B0)
unnamed: RN11.2 (R2.1), U5.17 (B1)
unnamed: RN11.3 (R3.1), U5.16 (B2)
unnamed: RN11.4 (R4.1), U5.15 (B3)
unnamed: RN12.1 (R1.1), U5.14 (B4)
unnamed: RN12.2 (R2.1), U5.13 (B5)
unnamed: RN12.3 (R3.1), U5.12 (B6)
unnamed: RN12.4 (R4.1), U5.11 (B7)
unnamed: RN13.1 (R1.1), U6.18 (B0)
unnamed: RN13.2 (R2.1), U6.17 (B1)
unnamed: RN13.3 (R3.1), U6.16 (B2)
unnamed: RN13.4 (R4.1), U6.15 (B3)
PD_GND: J3.E (GND), J3.F (GND), J3.H (GND), J3.J (GND), J3.K (GND), J3.L (GND), J3.M (GND), J3.N (GND), J25.1, J25.2; also elsewhere on the board

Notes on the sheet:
This is an approximation of the MC3446 transciever using commonly available parts. The MC3446 internally used a 2.4k/5k voltage divider. We substitute the more common values of 4.7k/10k. '07 drivers can sink 40ma, which is close to IEEE standard of 48ma. '245 recievers provide: • TTL → CMOS level c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

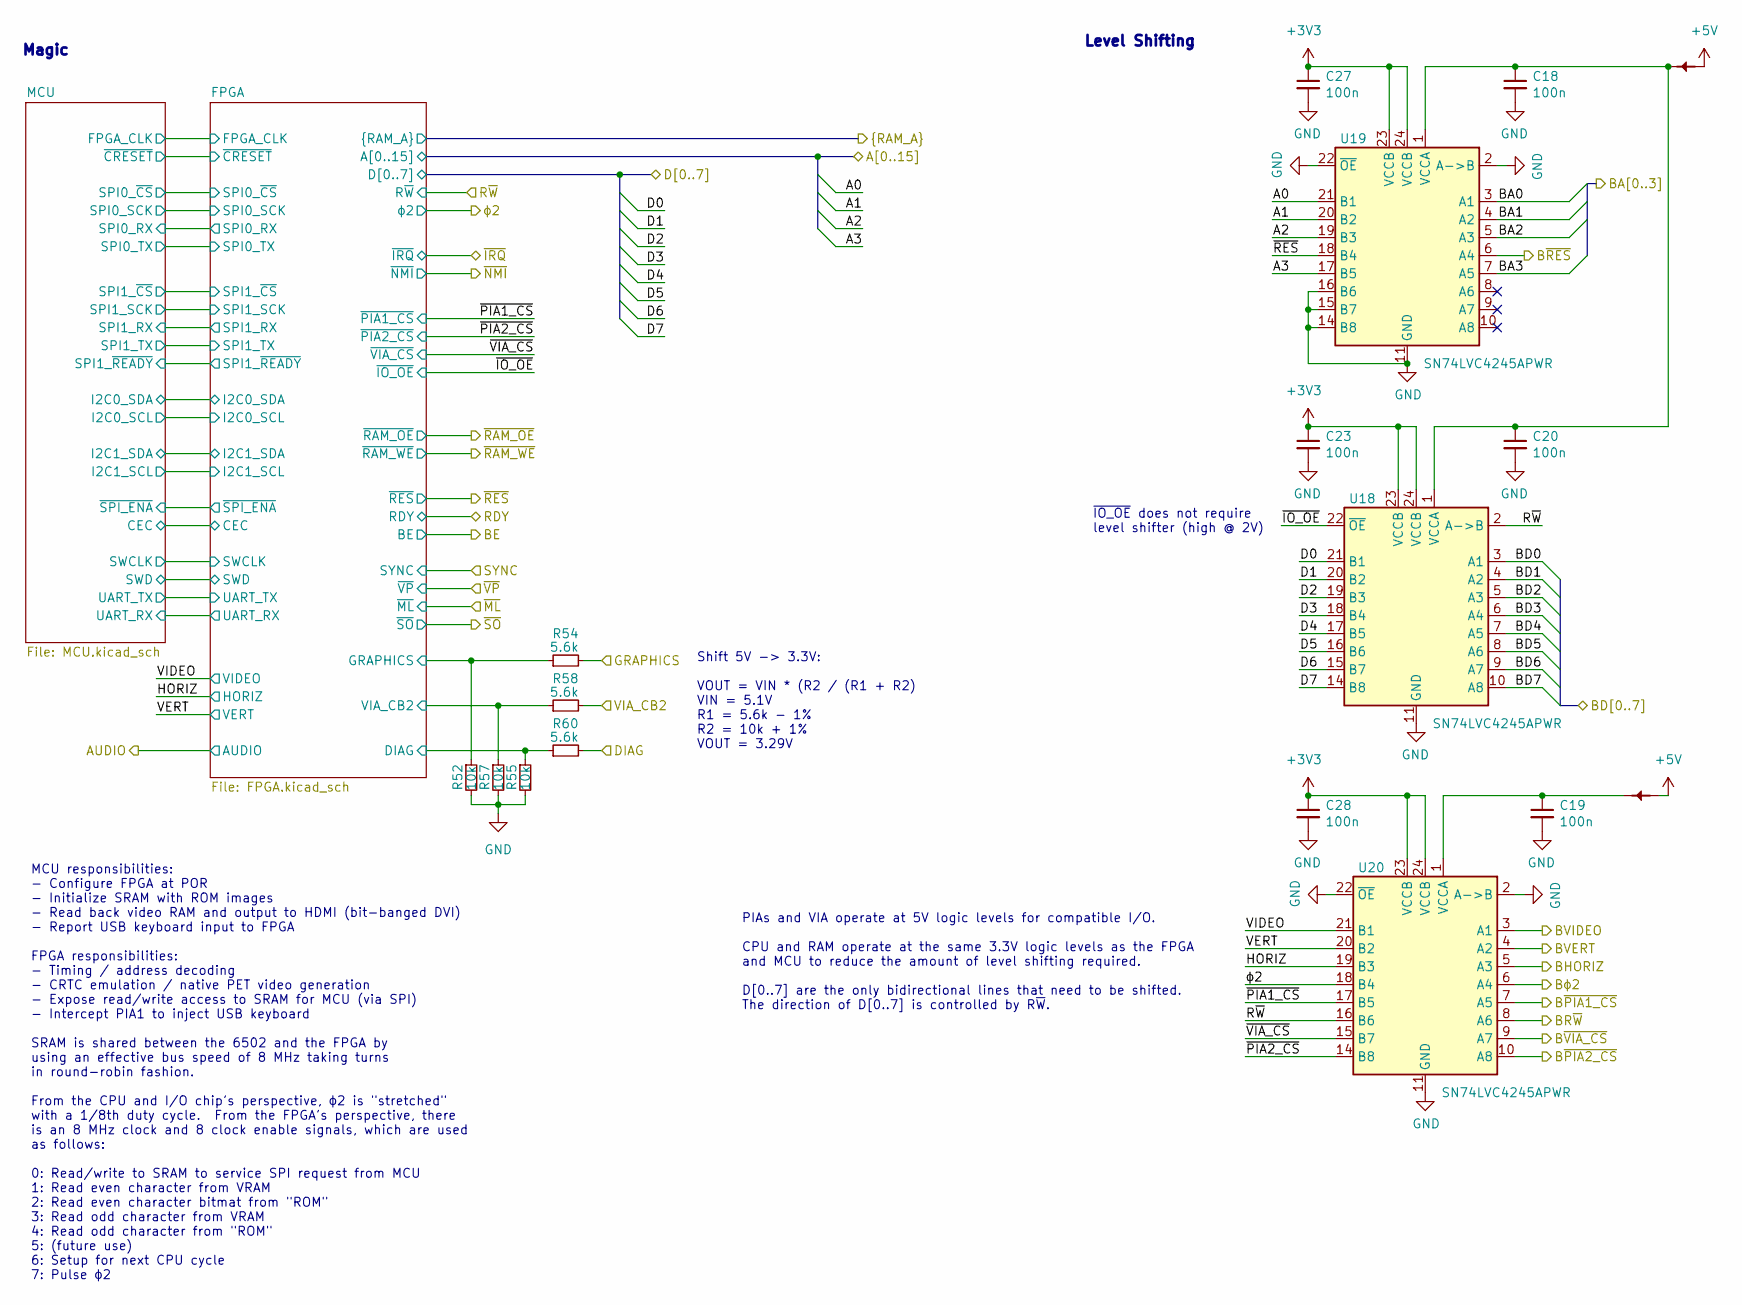
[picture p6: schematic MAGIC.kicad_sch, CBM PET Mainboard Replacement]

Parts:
C18, C19, C20, C23, C27, C28: 100n; C_0402_1005Metric; LCSC C1525
PT12, PT13: PowerTie_2; NetTie-2_SMD_Pad_1.6_to_0.4mm
R52, R55, R57: 10k; R_0402_1005Metric; LCSC C25744
R54, R58, R60: 5.6k; R_0402_1005Metric; LCSC C25908
U18, U19, U20: SN74LVC4245APWR; TSSOP-24_4.4x7.8mm_P0.65mm; LCSC C7859

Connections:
+3V3: C23.1, C27.1, C28.1, U18.23 (VCCB), U18.24 (VCCB), U19.23 (VCCB), U19.24 (VCCB), U20.23 (VCCB), U20.24 (VCCB); also elsewhere on the board
+5V: PT12.1, PT13.1; also elsewhere on the board
/CPU \ RAM/A0: U19.21 (B1); also elsewhere on the board
/CPU \ RAM/A1: U19.20 (B2); also elsewhere on the board
/CPU \ RAM/A2: U19.19 (B3); also elsewhere on the board
/CPU \ RAM/A3: U19.17 (B5); also elsewhere on the board
/CPU \ RAM/D0: U18.21 (B1); also elsewhere on the board
/CPU \ RAM/D1: U18.20 (B2); also elsewhere on the board
/CPU \ RAM/D2: U18.19 (B3); also elsewhere on the board
/CPU \ RAM/D3: U18.18 (B4); also elsewhere on the board
/CPU \ RAM/D4: U18.17 (B5); also elsewhere on the board
/CPU \ RAM/D5: U18.16 (B6); also elsewhere on the board
/CPU \ RAM/D6: U18.15 (B7); also elsewhere on the board
/CPU \ RAM/D7: U18.14 (B8); also elsewhere on the board
/CPU \ RAM/~RES: U19.18 (B4); also elsewhere on the board
/IEEE/IFC_OUT: U19.6 (A4); also elsewhere on the board
/IO/BA0: U19.3 (A1); also elsewhere on the board
/IO/BA1: U19.4 (A2); also elsewhere on the board
/IO/BA2: U19.5 (A3); also elsewhere on the board
/IO/BA3: U19.7 (A5); also elsewhere on the board
/IO/BD0: U18.3 (A1); also elsewhere on the board
/IO/BD1: U18.4 (A2); also elsewhere on the board
/IO/BD2: U18.5 (A3); also elsewhere on the board
/IO/BD3: U18.6 (A4); also elsewhere on the board
/IO/BD4: U18.7 (A5); also elsewhere on the board
/IO/BD5: U18.8 (A6); also elsewhere on the board
/IO/BD6: U18.9 (A7); also elsewhere on the board
/IO/BD7: U18.10 (A8); also elsewhere on the board
/IO/BR~W: U20.8 (A6); also elsewhere on the board
/IO/BVERT: U20.4 (A2); also elsewhere on the board
/IO/B~PIA1_CS: U20.7 (A5); also elsewhere on the board
/IO/B~PIA2_CS: U20.10 (A8); also elsewhere on the board
/IO/B~VIA_CS: U20.9 (A7); also elsewhere on the board
/IO/Bϕ2: U20.6 (A4); also elsewhere on the board
/IO/DIAG: R60.2; also elsewhere on the board
/IO/GRAPHIC: R54.2; also elsewhere on the board
/IO/VIA_CB2: R58.2; also elsewhere on the board
/MAGIC/BHORIZ: U20.5 (A3); also elsewhere on the board
/MAGIC/BVIDEO: U20.3 (A1); also elsewhere on the board
/MAGIC/FPGA/DIAG: R55.1, R60.1; also elsewhere on the board
/MAGIC/FPGA/GRAPHICS: R52.1, R54.1; also elsewhere on the board
/MAGIC/FPGA/VIA_CB2: R57.1, R58.1; also elsewhere on the board
/MAGIC/HORIZ: U20.19 (B3); also elsewhere on the board
/MAGIC/R~W: U18.2 (A->B), U20.16 (B6); also elsewhere on the board
/MAGIC/VERT: U20.20 (B2); also elsewhere on the board
/MAGIC/VIDEO: U20.21 (B1); also elsewhere on the board
/MAGIC/~IO_OE: U18.22 (~OE); also elsewhere on the board
/MAGIC/~PIA1_CS: U20.17 (B5); also elsewhere on the board
/MAGIC/~PIA2_CS: U20.14 (B8); also elsewhere on the board
/MAGIC/~VIA_CS: U20.15 (B7); also elsewhere on the board
/MAGIC/ϕ2: U20.18 (B4); also elsewhere on the board
GND: C18.2, C19.2, C20.2, C23.2, C27.2, C28.2, R52.2, R55.2, R57.2, U18.11 (GND), U18.12 (GND), U18.13 (GND), U19.2 (A->B), U19.11 (GND), U19.12 (GND), U19.13 (GND), U19.14 (B8), U19.15 (B7), U19.16 (B6), U19.22 (~OE), U20.2 (A->B), U20.11 (GND), U20.12 (GND), U20.13 (GND), U20.22 (~OE); also elsewhere on the board
unnamed: C18.1, C20.1, PT12.2, U18.1 (VCCA), U19.1 (VCCA)
unnamed: C19.1, PT13.2, U20.1 (VCCA)

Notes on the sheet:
PIAs and VIA operate at 5V logic levels for compatible I/O. CPU and RAM operate at the same 3.3V logic levels as the FPGA and MCU to reduce the amount of level shifting required. D[0..7] are the only bidirectional lines that need to be shifted. The direction of D[0..7] is controlled by R~{W}.
Level Shifting
Magic
MCU responsibilities: - Configure FPGA at POR - Initialize SRAM with ROM images - Read back video RAM and output to HDMI (bit-banged DVI) - Report USB keyboard input to FPGA FPGA responsibilities: - Timing / address decoding - CRTC emulation / native PET video generation - Expose read/write access 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
~{IO_OE} does not require level shifter (high @ 2V)
Shift 5V -> 3.3V: VOUT = VIN * (R2 / (R1 + R2) VIN = 5.1V R1 = 5.6k - 1% R2 = 10k + 1% VOUT = 3.29V

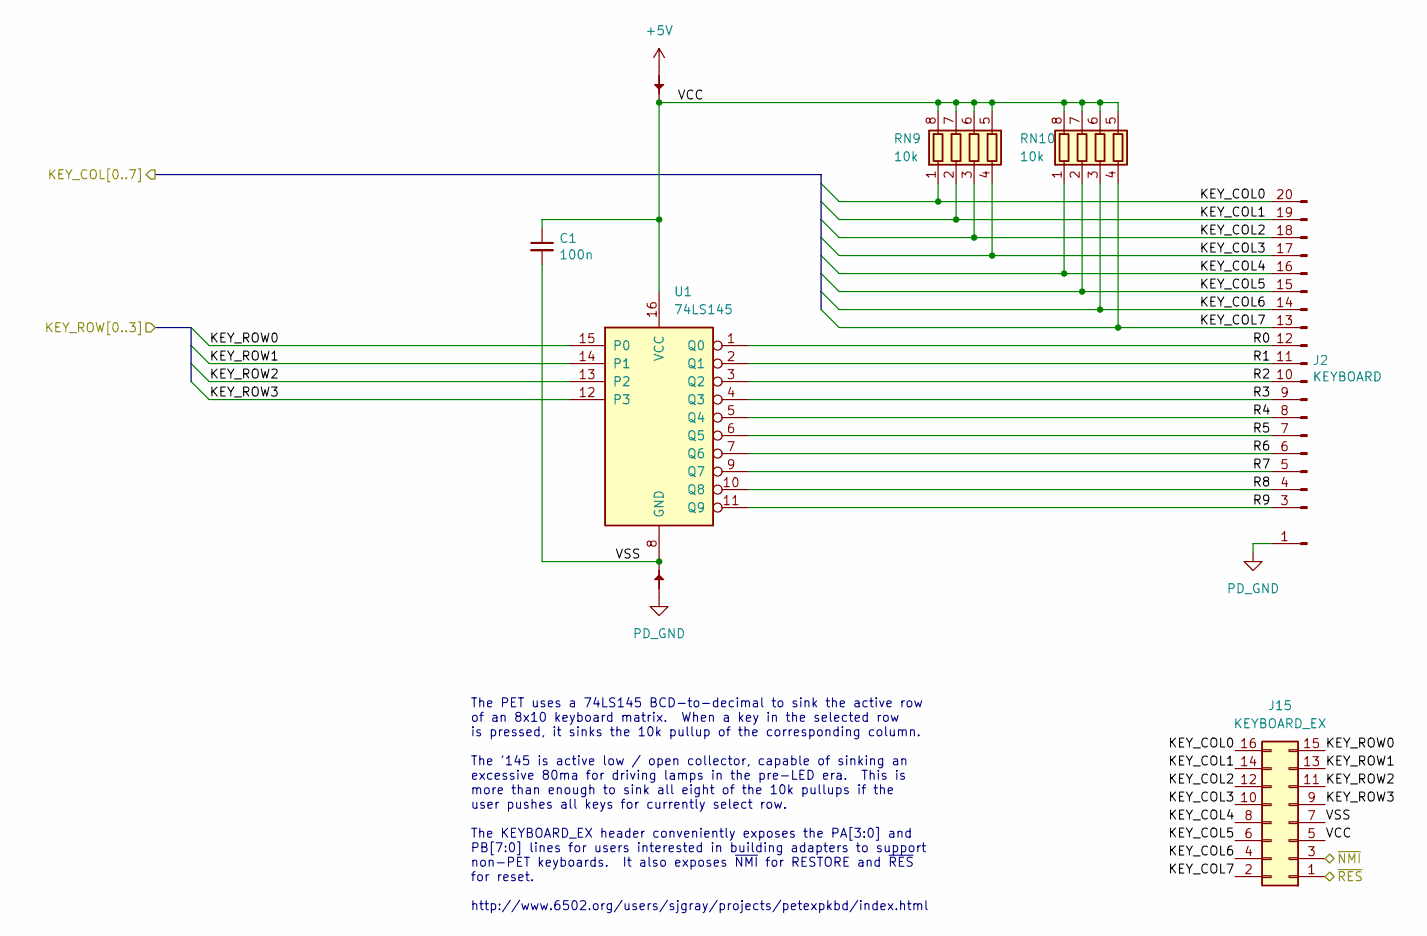
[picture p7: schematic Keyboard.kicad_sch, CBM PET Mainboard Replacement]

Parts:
C1: 100n; C_0402_1005Metric; LCSC C1525
J2: KEYBOARD; CBM_PET_KEYBOARD_KEYED_20P; MPN 2-826646-0
J15: KEYBOARD_EX; PinHeader_2x08_P2.54mm_Vertical
PT17, PT33: PowerTie_2; NetTie-2_SMD_Pad_1.6_to_0.4mm
RN9, RN10: 10k; R_Array_Convex_4x0603; LCSC C29718
U1: 74LS145; SOIC-16_3.9x9.9mm_P1.27mm; LCSC C60829

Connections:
+5V: PT17.1; also elsewhere on the board
/CPU \ RAM/~NMI: J15.3; also elsewhere on the board
/CPU \ RAM/~RES: J15.1; also elsewhere on the board
/IO/KEY_COL0: J2.20, J15.16, RN9.1 (R1.1); also elsewhere on the board
/IO/KEY_COL1: J2.19, J15.14, RN9.2 (R2.1); also elsewhere on the board
/IO/KEY_COL2: J2.18, J15.12, RN9.3 (R3.1); also elsewhere on the board
/IO/KEY_COL3: J2.17, J15.10, RN9.4 (R4.1); also elsewhere on the board
/IO/KEY_COL4: J2.16, J15.8, RN10.1 (R1.1); also elsewhere on the board
/IO/KEY_COL5: J2.15, J15.6, RN10.2 (R2.1); also elsewhere on the board
/IO/KEY_COL6: J2.14, J15.4, RN10.3 (R3.1); also elsewhere on the board
/IO/KEY_COL7: J2.13, J15.2, RN10.4 (R4.1); also elsewhere on the board
/IO/KEY_ROW0: J15.15, U1.15 (P0); also elsewhere on the board
/IO/KEY_ROW1: J15.13, U1.14 (P1); also elsewhere on the board
/IO/KEY_ROW2: J15.11, U1.13 (P2); also elsewhere on the board
/IO/KEY_ROW3: J15.9, U1.12 (P3); also elsewhere on the board
/Keyboard/R0: J2.12, U1.1 (Q0)
/Keyboard/R1: J2.11, U1.2 (Q1)
/Keyboard/R2: J2.10, U1.3 (Q2)
/Keyboard/R3: J2.9, U1.4 (Q3)
/Keyboard/R4: J2.8, U1.5 (Q4)
/Keyboard/R5: J2.7, U1.6 (Q5)
/Keyboard/R6: J2.6, U1.7 (Q6)
/Keyboard/R7: J2.5, U1.9 (Q7)
/Keyboard/R8: J2.4, U1.10 (Q8)
/Keyboard/R9: J2.3, U1.11 (Q9)
/Keyboard/VCC: C1.1, J15.5, PT17.2, RN9.5 (R4.2), RN9.6 (R3.2), RN9.7 (R2.2), RN9.8 (R1.2), RN10.5 (R4.2), RN10.6 (R3.2), RN10.7 (R2.2), RN10.8 (R1.2), U1.16 (VCC)
/Keyboard/VSS: C1.2, J15.7, PT33.2, U1.8 (GND)
PD_GND: J2.1, PT33.1; also elsewhere on the board

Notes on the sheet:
The PET uses a 74LS145 BCD-to-decimal to sink the active row of an 8x10 keyboard matrix. When a key in the selected row is pressed, it sinks the 10k pullup of the corresponding column. The '145 is active low / open collector, capable of sinking an excessive 80ma for driving lamps in the pre-LED era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

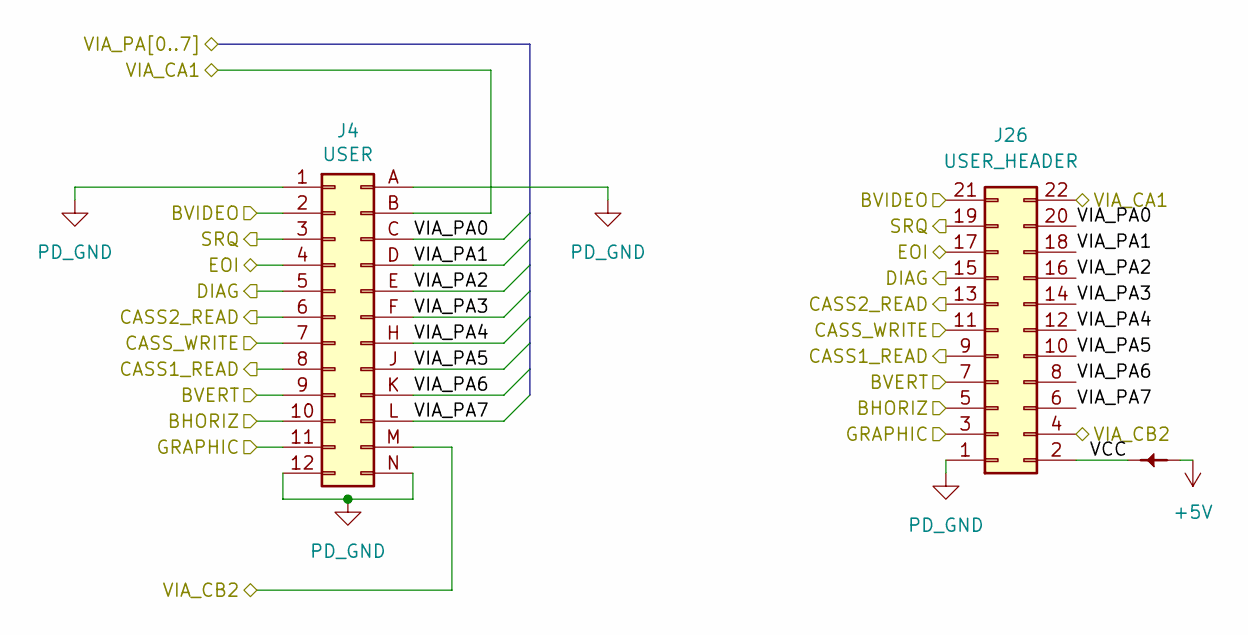
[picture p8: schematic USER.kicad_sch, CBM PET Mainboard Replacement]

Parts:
J4: USER; CBM_PET_USER_EDGE_CON_24P
J26: USER_HEADER; PinHeader_2x11_P2.54mm_Vertical
PT26: PowerTie_2; NetTie-2_SMD_Pad_1.6_to_0.4mm

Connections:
+5V: PT26.1; also elsewhere on the board
/CASS/CASS1_READ: J4.8 (CASS1_READ), J26.9; also elsewhere on the board
/CASS/CASS2_READ: J4.6 (CASS2_READ), J26.13; also elsewhere on the board
/CASS/CASS_WRITE: J4.7 (CASS_WRITE), J26.11; also elsewhere on the board
/IEEE/EOI: J4.4 (EOI), J26.17; also elsewhere on the board
/IEEE/SRQ: J4.3 (SRQ), J26.19; also elsewhere on the board
/IO/BVERT: J4.9 (VERT), J26.7; also elsewhere on the board
/IO/DIAG: J4.5 (DIAG), J26.15; also elsewhere on the board
/IO/GRAPHIC: J4.11 (GRAPHIC), J26.3; also elsewhere on the board
/IO/VIA_CA1: J4.B (VIA_CA1), J26.22; also elsewhere on the board
/IO/VIA_CB2: J4.M (VIA_CB2), J26.4; also elsewhere on the board
/IO/VIA_PA0: J4.C (VIA_PA0), J26.20; also elsewhere on the board
/IO/VIA_PA1: J4.D (VIA_PA1), J26.18; also elsewhere on the board
/IO/VIA_PA2: J4.E (VIA_PA2), J26.16; also elsewhere on the board
/IO/VIA_PA3: J4.F (VIA_PA3), J26.14; also elsewhere on the board
/IO/VIA_PA4: J4.H (VIA_PA4), J26.12; also elsewhere on the board
/IO/VIA_PA5: J4.J (VIA_PA5), J26.10; also elsewhere on the board
/IO/VIA_PA6: J4.K (VIA_PA6), J26.8; also elsewhere on the board
/IO/VIA_PA7: J4.L (VIA_PA7), J26.6; also elsewhere on the board
/MAGIC/BHORIZ: J4.10 (HORIZ), J26.5; also elsewhere on the board
/MAGIC/BVIDEO: J4.2 (~VIDEO), J26.21; also elsewhere on the board
/USER/VCC: J26.2, PT26.2
PD_GND: J4.1 (GND), J4.12 (GND), J4.A (GND), J4.N (GND), J26.1; also elsewhere on the board

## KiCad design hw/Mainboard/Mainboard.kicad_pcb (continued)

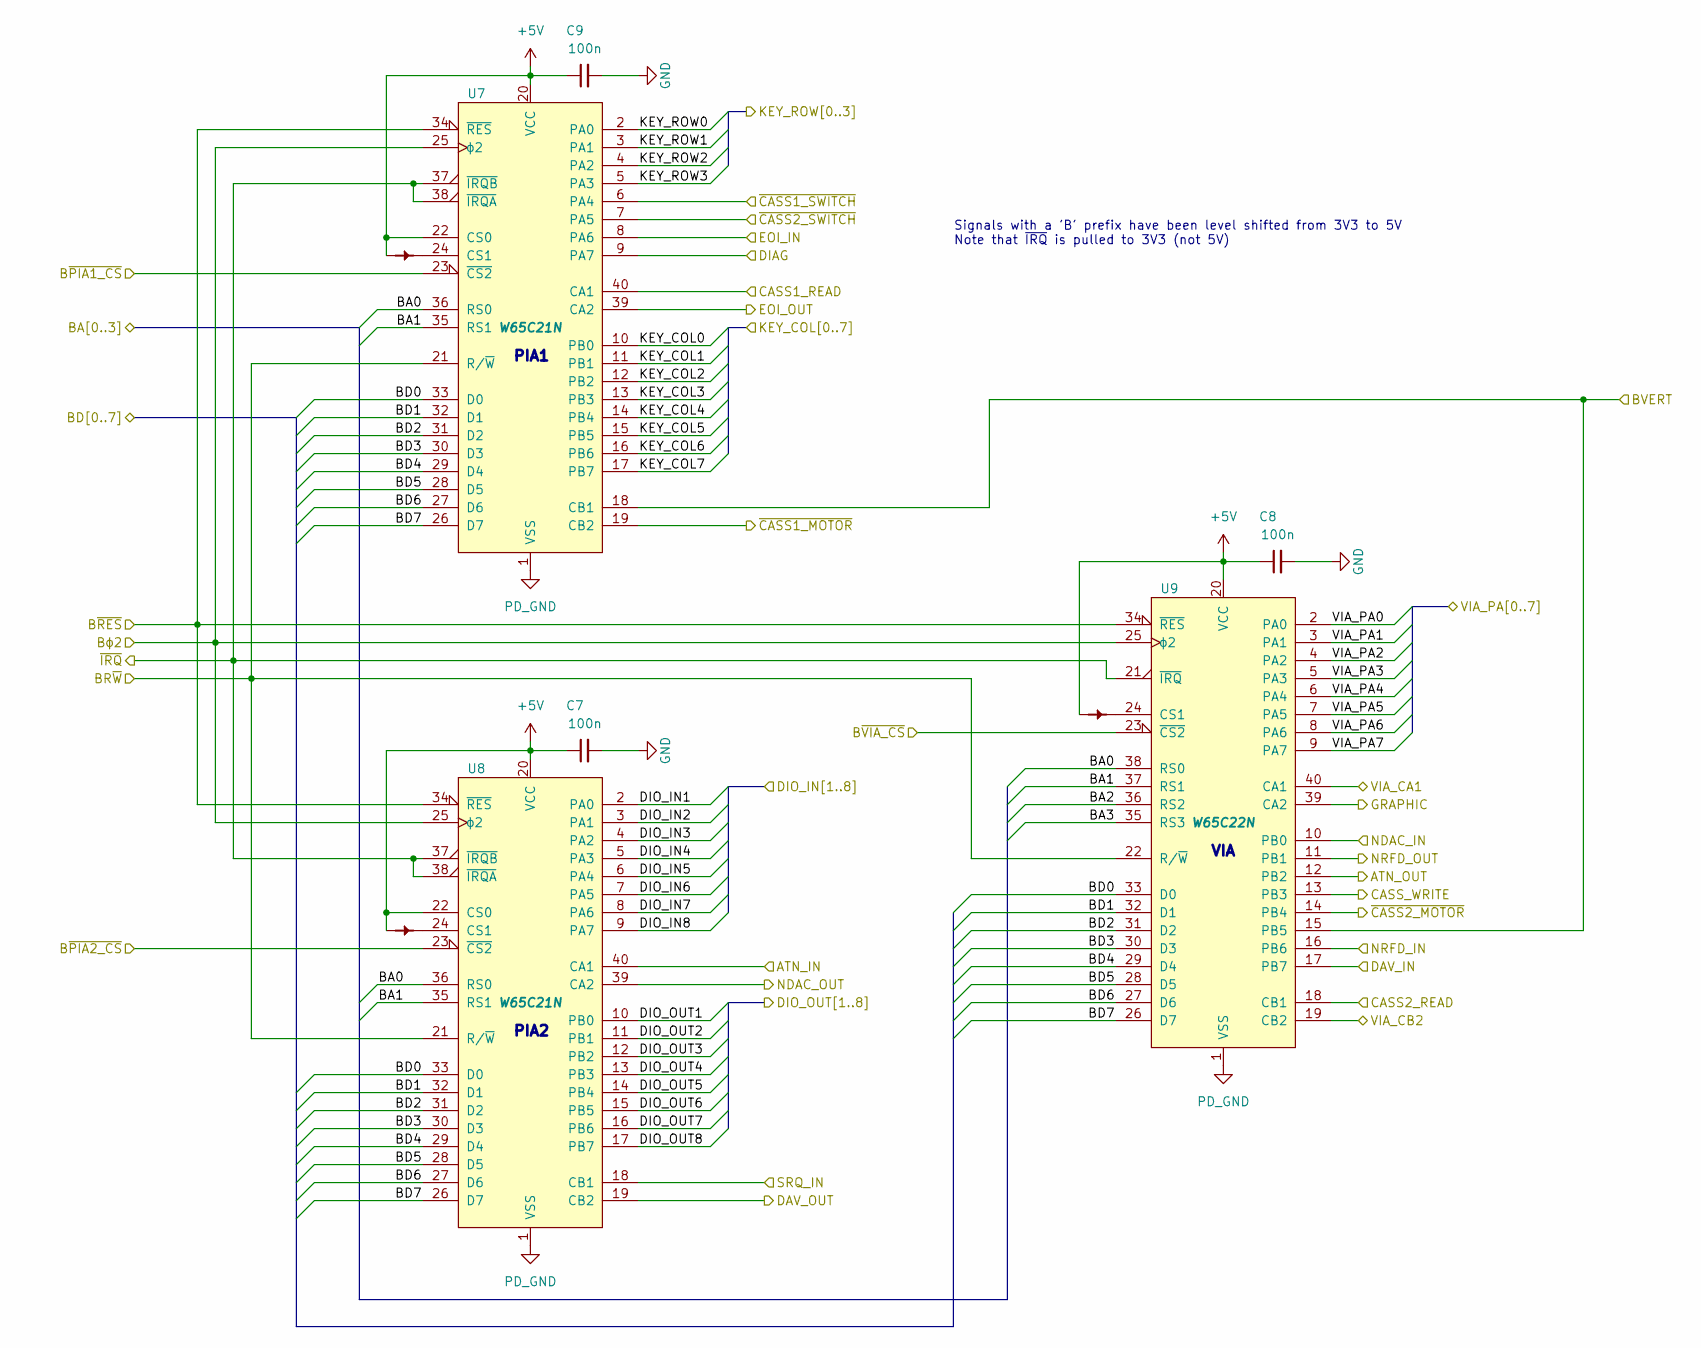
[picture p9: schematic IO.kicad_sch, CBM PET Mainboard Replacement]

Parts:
C7, C8, C9: 100n; C_0402_1005Metric; LCSC C1525
PT6, PT7, PT8: PowerTie_2; NetTie-2_SMD_Pad_1.6_to_0.4mm
U7, U8: W65C21N; DIP-40_W15.24mm_Socket; MOUSER 955-W65C21N6TPG-14
U9: W65C22N; DIP-40_W15.24mm_Socket; MOUSER 955-W65C22N6TPG-14

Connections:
+5V: C7.1, C8.1, C9.1, PT6.1, PT7.1, PT8.1, U7.20 (VCC), U7.22 (CS0), U8.20 (VCC), U8.22 (CS0), U9.20 (VCC); also elsewhere on the board
/CASS/CASS1_READ: U7.40 (CA1); also elsewhere on the board
/CASS/CASS2_READ: U9.18 (CB1); also elsewhere on the board
/CASS/CASS_WRITE: U9.13 (PB3); also elsewhere on the board
/CASS/~CASS1_MOTOR: U7.19 (CB2); also elsewhere on the board
/CASS/~CASS1_SWITCH: U7.6 (PA4); also elsewhere on the board
/CASS/~CASS2_MOTOR: U9.14 (PB4); also elsewhere on the board
/CASS/~CASS2_SWITCH: U7.7 (PA5); also elsewhere on the board
/IEEE/ATN_IN: U8.40 (CA1); also elsewhere on the board
/IEEE/ATN_OUT: U9.12 (PB2); also elsewhere on the board
/IEEE/DAV_IN: U9.17 (PB7); also elsewhere on the board
/IEEE/DAV_OUT: U8.19 (CB2); also elsewhere on the board
/IEEE/DIO_IN1: U8.2 (PA0); also elsewhere on the board
/IEEE/DIO_IN2: U8.3 (PA1); also elsewhere on the board
/IEEE/DIO_IN3: U8.4 (PA2); also elsewhere on the board
/IEEE/DIO_IN4: U8.5 (PA3); also elsewhere on the board
/IEEE/DIO_IN5: U8.6 (PA4); also elsewhere on the board
/IEEE/DIO_IN6: U8.7 (PA5); also elsewhere on the board
/IEEE/DIO_IN7: U8.8 (PA6); also elsewhere on the board
/IEEE/DIO_IN8: U8.9 (PA7); also elsewhere on the board
/IEEE/DIO_OUT1: U8.10 (PB0); also elsewhere on the board
/IEEE/DIO_OUT2: U8.11 (PB1); also elsewhere on the board
/IEEE/DIO_OUT3: U8.12 (PB2); also elsewhere on the board
/IEEE/DIO_OUT4: U8.13 (PB3); also elsewhere on the board
/IEEE/DIO_OUT5: U8.14 (PB4); also elsewhere on the board
/IEEE/DIO_OUT6: U8.15 (PB5); also elsewhere on the board
/IEEE/DIO_OUT7: U8.16 (PB6); also elsewhere on the board
/IEEE/DIO_OUT8: U8.17 (PB7); also elsewhere on the board
/IEEE/EOI_IN: U7.8 (PA6); also elsewhere on the board
/IEEE/EOI_OUT: U7.39 (CA2); also elsewhere on the board
/IEEE/IFC_OUT: U7.34 (~RES), U8.34 (~RES), U9.34 (~RES); also elsewhere on the board
/IEEE/NDAC_IN: U9.10 (PB0); also elsewhere on the board
/IEEE/NDAC_OUT: U8.39 (CA2); also elsewhere on the board
/IEEE/NRFD_IN: U9.16 (PB6); also elsewhere on the board
/IEEE/NRFD_OUT: U9.11 (PB1); also elsewhere on the board
/IEEE/SRQ_IN: U8.18 (CB1); also elsewhere on the board
/IO/BA0: U7.36 (RS0), U8.36 (RS0), U9.38 (RS0); also elsewhere on the board
/IO/BA1: U7.35 (RS1), U8.35 (RS1), U9.37 (RS1); also elsewhere on the board
/IO/BA2: U9.36 (RS2); also elsewhere on the board
/IO/BA3: U9.35 (RS3); also elsewhere on the board
/IO/BD0: U7.33 (D0), U8.33 (D0), U9.33 (D0); also elsewhere on the board
/IO/BD1: U7.32 (D1), U8.32 (D1), U9.32 (D1); also elsewhere on the board
/IO/BD2: U7.31 (D2), U8.31 (D2), U9.31 (D2); also elsewhere on the board
/IO/BD3: U7.30 (D3), U8.30 (D3), U9.30 (D3); also elsewhere on the board
/IO/BD4: U7.29 (D4), U8.29 (D4), U9.29 (D4); also elsewhere on the board
/IO/BD5: U7.28 (D5), U8.28 (D5), U9.28 (D5); also elsewhere on the board
/IO/BD6: U7.27 (D6), U8.27 (D6), U9.27 (D6); also elsewhere on the board
/IO/BD7: U7.26 (D7), U8.26 (D7), U9.26 (D7); also elsewhere on the board
/IO/BR~W: U7.21 (R/~W), U8.21 (R/~W), U9.22 (R/~W); also elsewhere on the board
/IO/BVERT: U7.18 (CB1), U9.15 (PB5); also elsewhere on the board
/IO/B~PIA1_CS: U7.23 (~CS2); also elsewhere on the board
/IO/B~PIA2_CS: U8.23 (~CS2); also elsewhere on the board
/IO/B~VIA_CS: U9.23 (~CS2); also elsewhere on the board
/IO/Bϕ2: U7.25 (ϕ2), U8.25 (ϕ2), U9.25 (ϕ2); also elsewhere on the board
/IO/DIAG: U7.9 (PA7); also elsewhere on the board
/IO/GRAPHIC: U9.39 (CA2); also elsewhere on the board
/IO/KEY_COL0: U7.10 (PB0); also elsewhere on the board
/IO/KEY_COL1: U7.11 (PB1); also elsewhere on the board
/IO/KEY_COL2: U7.12 (PB2); also elsewhere on the board
/IO/KEY_COL3: U7.13 (PB3); also elsewhere on the board
/IO/KEY_COL4: U7.14 (PB4); also elsewhere on the board
/IO/KEY_COL5: U7.15 (PB5); also elsewhere on the board
/IO/KEY_COL6: U7.16 (PB6); also elsewhere on the board
/IO/KEY_COL7: U7.17 (PB7); also elsewhere on the board
/IO/KEY_ROW0: U7.2 (PA0); also elsewhere on the board
/IO/KEY_ROW1: U7.3 (PA1); also elsewhere on the board
/IO/KEY_ROW2: U7.4 (PA2); also elsewhere on the board
/IO/KEY_ROW3: U7.5 (PA3); also elsewhere on the board
/IO/VIA_CA1: U9.40 (CA1); also elsewhere on the board
/IO/VIA_CB2: U9.19 (CB2); also elsewhere on the board
/IO/VIA_PA0: U9.2 (PA0); also elsewhere on the board
/IO/VIA_PA1: U9.3 (PA1); also elsewhere on the board
/IO/VIA_PA2: U9.4 (PA2); also elsewhere on the board
/IO/VIA_PA3: U9.5 (PA3); also elsewhere on the board
/IO/VIA_PA4: U9.6 (PA4); also elsewhere on the board
/IO/VIA_PA5: U9.7 (PA5); also elsewhere on the board
/IO/VIA_PA6: U9.8 (PA6); also elsewhere on the board
/IO/VIA_PA7: U9.9 (PA7); also elsewhere on the board
/MAGIC/FPGA/~IRQ: U7.37 (~IRQB), U7.38 (~IRQA), U8.37 (~IRQB), U8.38 (~IRQA), U9.21 (~IRQ); also elsewhere on the board
GND: C7.2, C8.2, C9.2; also elsewhere on the board
unnamed: PT6.2, U7.24 (CS1)
unnamed: PT7.2, U9.24 (CS1)
unnamed: PT8.2, U8.24 (CS1)
PD_GND: U7.1 (VSS), U8.1 (VSS), U9.1 (VSS); also elsewhere on the board

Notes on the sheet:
PIA1
PIA2
Signals with a 'B' prefix have been level shifted from 3V3 to 5V Note that ~{IRQ} is pulled to 3V3 (not 5V)
VIA

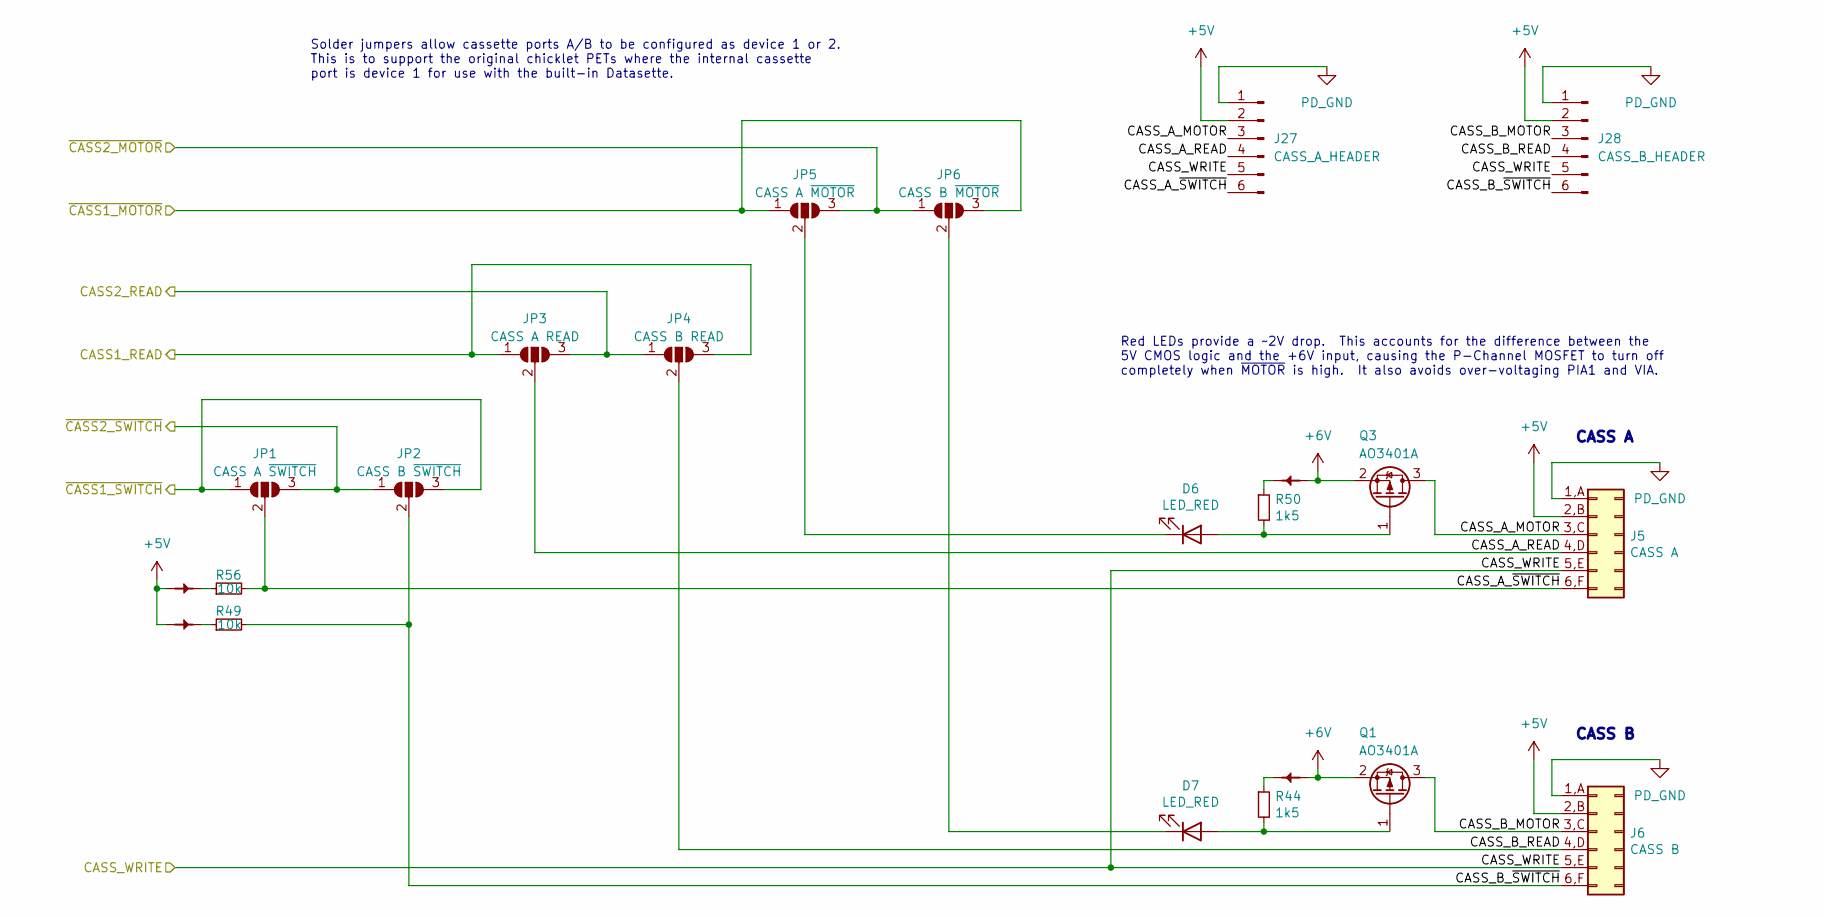
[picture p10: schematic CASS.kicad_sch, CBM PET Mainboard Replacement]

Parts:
D6, D7: LED_RED; LED_0603_1608Metric; LCSC C2286
J5: CASS A; CBM_PET_CASS_EDGE_CON_12P
J6: CASS B; CBM_PET_CASS_EDGE_CON_12P
J27: CASS_A_HEADER; PinHeader_1x06_P2.54mm_Vertical
J28: CASS_B_HEADER; PinHeader_1x06_P2.54mm_Vertical
JP1: CASS A ~{SWITCH}; SolderJumper-3_P1.3mm_Bridged12_RoundedPad1.0x1.5mm
JP2: CASS B ~{SWITCH}; SolderJumper-3_P1.3mm_Bridged12_RoundedPad1.0x1.5mm
JP3: CASS A READ; SolderJumper-3_P1.3mm_Bridged12_RoundedPad1.0x1.5mm
JP4: CASS B READ; SolderJumper-3_P1.3mm_Bridged12_RoundedPad1.0x1.5mm
JP5: CASS A ~{MOTOR}; SolderJumper-3_P1.3mm_Bridged12_RoundedPad1.0x1.5mm
JP6: CASS B ~{MOTOR}; SolderJumper-3_P1.3mm_Bridged12_RoundedPad1.0x1.5mm
PT15, PT16, PT21, PT22: PowerTie_2; NetTie-2_SMD_Pad_1.6_to_0.4mm
Q1, Q3: AO3401A; SOT-23_L2.9-W1.3-P1.90-LS2.4-BR; LCSC C15127
R44, R50: 1k5; R_0402_1005Metric; LCSC C25867
R49, R56: 10k; R_0402_1005Metric; LCSC C25744

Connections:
+5V: J5.2,B (+5V), J6.2,B (+5V), J27.2, J28.2, PT15.1, PT16.1; also elsewhere on the board
+6V: PT21.1, PT22.1, Q1.2 (S), Q3.2 (S); also elsewhere on the board
/CASS/CASS1_READ: JP3.1 (A), JP4.3 (B); also elsewhere on the board
/CASS/CASS2_READ: JP3.3 (B), JP4.1 (A); also elsewhere on the board
/CASS/CASS_A_MOTOR: J5.3,C (MOTOR), J27.3, Q3.3 (D)
/CASS/CASS_A_READ: J5.4,D (READ), J27.4, JP3.2 (C)
/CASS/CASS_A_~SWITCH: J5.6,F (SWITCH), J27.6, JP1.2 (C), R56.2
/CASS/CASS_B_MOTOR: J6.3,C (MOTOR), J28.3, Q1.3 (D)
/CASS/CASS_B_READ: J6.4,D (READ), J28.4, JP4.2 (C)
/CASS/CASS_B_~SWITCH: J6.6,F (SWITCH), J28.6, JP2.2 (C), R49.2
/CASS/CASS_WRITE: J5.5,E (WRITE), J6.5,E (WRITE), J27.5, J28.5; also elsewhere on the board
/CASS/~CASS1_MOTOR: JP5.1 (A), JP6.3 (B); also elsewhere on the board
/CASS/~CASS1_SWITCH: JP1.1 (A), JP2.3 (B); also elsewhere on the board
/CASS/~CASS2_MOTOR: JP5.3 (B), JP6.1 (A); also elsewhere on the board
/CASS/~CASS2_SWITCH: JP1.3 (B), JP2.1 (A); also elsewhere on the board
unnamed: D6.1 (K), JP5.2 (C)
unnamed: D6.2 (A), Q3.1 (G), R50.2
unnamed: D7.1 (K), JP6.2 (C)
unnamed: D7.2 (A), Q1.1 (G), R44.2
unnamed: PT15.2, R56.1
unnamed: PT16.2, R49.1
unnamed: PT21.2, R50.1
unnamed: PT22.2, R44.1
PD_GND: J5.1,A (GND), J6.1,A (GND), J27.1, J28.1; also elsewhere on the board

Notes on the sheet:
Solder jumpers allow cassette ports A/B to be configured as device 1 or 2. This is to support the original chicklet PETs where the internal cassette port is device 1 for use with the built-in Datasette.
CASS B
Red LEDs provide a ~2V drop. This accounts for the difference between the 5V CMOS logic and the +6V input, causing the P-Channel MOSFET to turn off completely when ~{MOTOR} is high. It also avoids over-voltaging PIA1 and VIA.
CASS A

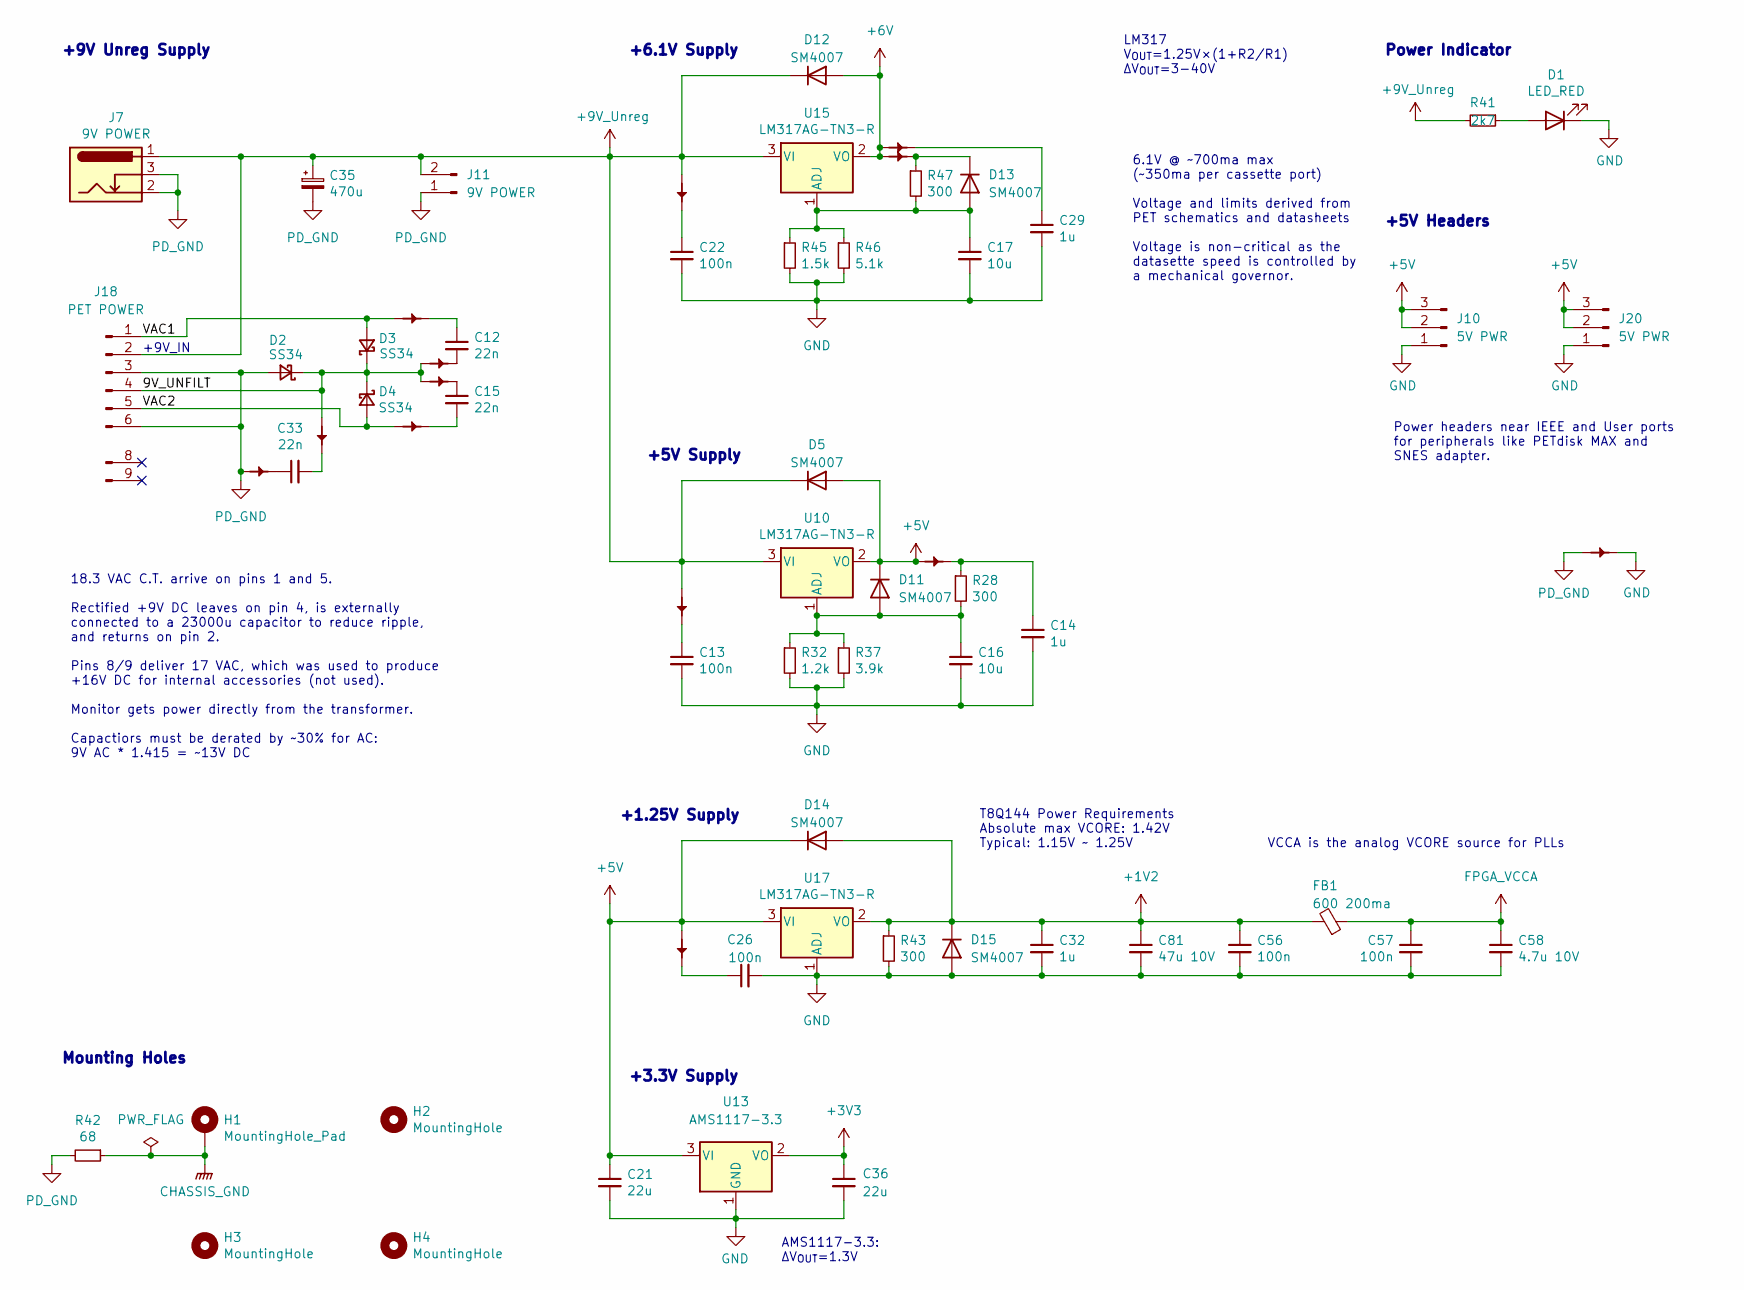
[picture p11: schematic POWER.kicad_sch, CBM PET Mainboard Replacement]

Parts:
C12, C15, C33: 22n; C_0402_1005Metric; LCSC C1532
C13, C22, C26: 100n; C_0402_1005Metric; LCSC C307331
C14, C29, C32: 1u; C_0402_1005Metric; LCSC C52923
C16, C17: 10u; C_0603_1608Metric; LCSC C96446
C21, C36: 22u; C_0805_2012Metric; LCSC C45783
C35: 470u; CP_Radial_D16.0mm_P5.00mm_P7.50mm; MPN 35YXJ470M10X16; MOUSER 232-35YXJ470M10X16
C56, C57: 100n; C_0402_1005Metric; LCSC C1525
C58: 4.7u 10V; C_0402_1005Metric; LCSC C23733
C81: 47u 10V; C_1206_3216Metric; LCSC C96123
D1: LED_RED; LED_0603_1608Metric; LCSC C2286
D2, D3, D4: SS34; D_SMA; LCSC C8678
D5, D11, D12, D13, D14, D15: SM4007; D_SOD-123F; LCSC C64898
FB1: 600 200ma; L_0603_1608Metric; LCSC C1002
H1: MountingHole_Pad; MountingHole_4mm_Pad
H2, H3, H4: MountingHole; PET_MountingHole_4mm
J7: 9V POWER; BarrelJack_Horizontal; MPN CON-SOCJ-2155; MOUSER 992-CON-SOCJ-2155
J10, J20: 5V PWR; PinHeader_1x03_P2.54mm_Vertical
J11: 9V POWER; PinHeader_1x02_P2.54mm_Vertical
J18: PET POWER; PET_POWER_Molex_KK-396_A-41791-0009_1x09_P3.96mm_Vertical; MOUSER 571-6403849
PT3, PT4, PT9, PT14, PT23, PT24, PT25, PT27, PT28, PT29, PT30, PT31, PT32: PowerTie_2; NetTie-2_SMD_Pad_1.6_to_0.4mm
R28, R43, R47: 300; R_0402_1005Metric; LCSC C25102
R32: 1.2k; R_0402_1005Metric; LCSC C25862
R37: 3.9k; R_0402_1005Metric; LCSC C51721
R41: 2k7; R_0603_1608Metric; LCSC C13167
R42: 68; R_0805_2012Metric; LCSC C17802
R45: 1.5k; R_0402_1005Metric; LCSC C25867
R46: 5.1k; R_0402_1005Metric; LCSC C25905
U10: LM317AG-TN3-R; TO-252-2_ThermalVias; LCSC C75510
U13: AMS1117-3.3; SOT-223-3_TabPin2; LCSC C6186
U15, U17: LM317AG-TN3-R; TO-252-2; LCSC C75510

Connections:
+1V2: C32.1, C56.1, C81.1, D14.2 (A), D15.1 (K), FB1.2, R43.1, U17.2 (VO); also elsewhere on the board
+3V3: C36.1, U13.2 (VO); also elsewhere on the board
+5V: C21.1, D5.2 (A), D11.1 (K), D14.1 (K), J10.2, J10.3, J20.2, J20.3, PT3.1, PT14.1, U10.2 (VO), U13.3 (VI), U17.3 (VI); also elsewhere on the board
+6V: D12.2 (A), PT23.1, PT25.1, U15.2 (VO); also elsewhere on the board
+9V_Unreg: C35.1, D5.1 (K), D12.1 (K), J7.1, J11.2, J18.2 (9V_IN), PT4.1, PT24.1, R41.2, U10.3 (VI), U15.3 (VI)
/POWER/9V_UNFILT: D2.1 (K), D3.1 (K), D4.1 (K), J18.4 (9V_OUT), PT30.1, PT31.1, PT32.1
/POWER/VAC1: D3.2 (A), J18.1 (AC1), PT28.1
/POWER/VAC2: D4.2 (A), J18.5 (AC2), PT29.1
CHASSIS_GND: H1.1, R42.1; also elsewhere on the board
FPGA_VCCA: C57.1, C58.1, FB1.1; also elsewhere on the board
GND: C13.2, C14.2, C16.2, C17.2, C21.2, C22.2, C26.2, C29.2, C32.2, C36.2, C56.2, C57.2, C58.2, C81.2, D1.1 (K), D15.2 (A), J10.1, J20.1, PT9.2, R32.2, R37.2, R43.2, R45.2, R46.2, U13.1 (GND), U17.1 (ADJ); also elsewhere on the board
unnamed: C12.1, PT28.2
unnamed: C12.2, PT32.2
unnamed: C13.1, PT4.2
unnamed: C14.1, PT3.2, R28.1
unnamed: C15.1, PT30.2
unnamed: C15.2, PT29.2
unnamed: C16.1, D11.2 (A), R28.2, R32.1, R37.1, U10.1 (ADJ)
unnamed: C17.1, D13.2 (A), R45.1, R46.1, R47.2, U15.1 (ADJ)
unnamed: C22.1, PT24.2
unnamed: C26.1, PT14.2
unnamed: C29.1, PT25.2
unnamed: C33.1, PT27.2
unnamed: C33.2, PT31.2
unnamed: D1.2 (A), R41.1
unnamed: D13.1 (K), PT23.2, R47.1
PD_GND: C35.2, D2.2 (A), J7.2, J7.3, J11.1, J18.3 (GND), J18.6 (GND), PT9.1, PT27.1, R42.2; also elsewhere on the board

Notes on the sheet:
T8Q144 Power Requirements Absolute max VCORE: 1.42V Typical: 1.15V ~ 1.25V
18.3 VAC C.T. arrive on pins 1 and 5. Rectified +9V DC leaves on pin 4, is externally connected to a 23000u capacitor to reduce ripple, and returns on pin 2. Pins 8/9 deliver 17 VAC, which was used to produce +16V DC for internal accessories (not used). Monitor gets power directly from the transfor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
Power Indicator
+9V_IN
+9V Unreg Supply
+6.1V Supply
+5V Headers
+5V Supply
VCCA is the analog VCORE source for PLLs
AMS1117-3.3: ΔV_{OUT}=1.3V
Mounting Holes
Power headers near IEEE and User ports for peripherals like PETdisk MAX and SNES adapter.
+1.25V Supply
+3.3V Supply
6.1V @ ~700ma max (~350ma per cassette port) Voltage and limits derived from PET schematics and datasheets Voltage is non-critical as the datasette speed is controlled by a mechanical governor.
LM317 V_{OUT}=1.25V×(1+R2/R1) ΔV_{OUT}=3-40V

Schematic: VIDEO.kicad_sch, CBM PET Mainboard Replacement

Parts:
J9: VIDEO; PET_Video

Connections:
/IO/BVERT: J9.3 (VERT); also elsewhere on the board
/MAGIC/BHORIZ: J9.5 (HORIZ); also elsewhere on the board
/MAGIC/BVIDEO: J9.1 (GND); also elsewhere on the board
PD_GND: J9.2 (GND), J9.4 (GND), J9.7 (VIDEO); also elsewhere on the board

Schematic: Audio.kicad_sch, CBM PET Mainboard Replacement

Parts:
C30: 100n; C_0402_1005Metric; LCSC C1525
C31: 1u; C_0402_1005Metric; LCSC C52923
J1: SJ-43504-SMT-TR; CUI_SJ-43504-SMT-TR; MOUSER 490-SJ-43504-SMT-TR
J8: LINE_AUDIO; PinHeader_1x02_P2.54mm_Vertical
LS1: Speaker; AT1220TT9R; MOUSER 665-AT1220TT9R
R53: 4k7; R_0402_1005Metric; LCSC C25900
R61, R62: 220; R_0603_1608Metric; LCSC C22962
R72: 22k; R_0402_1005Metric; LCSC C25768
U22: 74HC04

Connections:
+3V3: C30.1, U22.14 (VCC); also elsewhere on the board
/MAGIC/FPGA/AUDIO: C31.1, R53.1; also elsewhere on the board
GND: C30.2, J1.1, J8.1, U22.7 (GND); also elsewhere on the board
unnamed: C31.2, R72.1
unnamed: J1.2, J1.3, R72.2
unnamed: J1.4, R53.2, U22.1, U22.3, U22.5
unnamed: J1.5, J1.6, J8.2
unnamed: LS1.1, R61.1
unnamed: LS1.2, R62.1
unnamed: R61.2, U22.2, U22.4, U22.6, U22.9, U22.11, U22.13
unnamed: R62.2, U22.8, U22.10, U22.12

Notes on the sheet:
The 74HC04 inverter servers as a buffer/driver with each output capable of sourcing/sinking 25ma. When ganged in parallel, it can push/pull 75ma simultaneously.
To silence the built-in speaker when an external amplifier is connected, we use pin 4 of the 3.5mm jack to pull down the audio input to the inverter. This is simpiler than using the line level audio passthrough from pins 5/6, which would need to be restored to 3V CMOS levels to drive the inverter.
The AUDIO source is a 3.3V square wave. (It is 3.3V instead of 5V as a consequence of using the FPGA to implement the NAND gate between CB2 and DIAG to save an IC.) Line-level audio for consumer electronics targets a voltage of +/- 0.5V. This is achieved by a voltage divider where the output provid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

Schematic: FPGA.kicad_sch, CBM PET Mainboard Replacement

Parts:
C60, C69: 1u; C_0402_1005Metric; LCSC C52923
C61, C62, C63, C64, C71, C72, C73, C75, C76, C77, C80: 100n; C_0402_1005Metric; LCSC C1525
C65, C66, C67, C68, C78, C79: 10n; C_0402_1005Metric; LCSC C15195
D8: LED_GRN; LED_0603_1608Metric; LCSC C72043
D9: LED_RED; LED_0603_1608Metric; LCSC C2286
J16: MCU; PinHeader_2x12_P2.54mm_Vertical
J19: PROG; IDC-Header_2x08_P2.54mm_Vertical; MOUSER 710-61201621621
J21: FPGA-P4; PinHeader_2x14_P2.54mm_Vertical; MPN 929975-01-14; DIGI-KEY SAM1204-14-ND
J23: FPGA_P2; PinHeader_2x14_P2.54mm_Vertical; MPN 929975-01-14; DIGI-KEY SAM1204-14-ND
J24: Conn_02x15_Odd_Even; PinHeader_2x15_P2.54mm_Vertical
Q4: MMBT3904; SOT-23; LCSC C20526
R27: 10k; R_0402_1005Metric; LCSC C25744
R29, R31: 1k; R_0402_1005Metric; LCSC C11702
R30, R33: 100k; R_0402_1005Metric; LCSC C25741
R34: 12k 1%; R_0402_1005Metric; LCSC C25752
R68, R70, R71: 33; R_0402_1005Metric; LCSC C25105
RN14, RN15: 10k; R_Array_Convex_4x0603; LCSC C29718
SW5: CONFIG; SW_DIP_SPSTx04_Slide_6.7x11.72mm_W7.62mm_P2.54mm_LowProfile; MOUSER 490-DS04-254-1L-04BK
U21: T8Q144C3; QFP50P2200X2200X160-144N; MPN T8Q144C3; DIGI-KEY 2134-T8Q144C3-ND

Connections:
+1V1: J16.2
+1V2: C60.1, C61.1, C62.1, C63.1, C64.1, C65.1, C66.1, C67.1, C68.1, U21.13 (VCC), U21.22 (VCC), U21.49 (VCC), U21.57 (VCC), U21.85 (VCC), U21.96 (VCC), U21.125 (VCC), U21.128 (VCC), U21.130 (VCC); also elsewhere on the board
+3V3: C69.1, C71.1, C72.1, C73.1, C75.1, C76.1, C77.1, C78.1, C79.1, C80.1, J16.24, R27.2, R29.2, RN14.5 (R4.2), RN14.6 (R3.2), RN14.7 (R2.2), RN14.8 (R1.2), RN15.5 (R4.2), RN15.6 (R3.2), RN15.7 (R2.2), RN15.8 (R1.2), U21.12 (VCCIO1C_1D), U21.21 (VCCIO1B), U21.23 (VCCIO1A), U21.51 (VCCIO4B), U21.52 (VCCIO4B), U21.62 (VCCIO4A), U21.63 (VCCIO4A), U21.88 (VCCIO3E), U21.91 (VCCIO3D), U21.95 (VCCIO3B_3C), U21.122 (VCCIO3A), U21.143 (VCCIO1E); also elsewhere on the board
+5V: J19.10; also elsewhere on the board
/CPU \ RAM/A0: J24.1, U21.70 (GPIOB_RXP12_EXTFB0); also elsewhere on the board
/CPU \ RAM/A1: J24.3, U21.72 (GPIOB_CLKN0); also elsewhere on the board
/CPU \ RAM/A2: J24.5, U21.75 (GPIOR_157_PLLIN); also elsewhere on the board
/CPU \ RAM/A3: J24.7, U21.81 (GPIOR_139); also elsewhere on the board
/CPU \ RAM/A4: J24.9, U21.83 (GPIOR_136_CDI16); also elsewhere on the board
/CPU \ RAM/A5: J24.11, U21.86 (GPIOR_133_CDI18); also elsewhere on the board
/CPU \ RAM/A6: J24.13, U21.89 (GPIOR_129_CTRL10); also elsewhere on the board
/CPU \ RAM/A7: J24.15, U21.92 (GPIOR_125_CLK10); also elsewhere on the board
/CPU \ RAM/A8: J24.17, U21.100 (GPIOR_113_CDI22); also elsewhere on the board
/CPU \ RAM/A9: J24.19, U21.102 (GPIOR_105_CDI24); also elsewhere on the board
/CPU \ RAM/A10: J24.21, U21.105 (GPIOR_95_CDI26); also elsewhere on the board
/CPU \ RAM/A11: J24.25, U21.111 (GPIOR_85); also elsewhere on the board
/CPU \ RAM/A12: J24.2, U21.69 (GPIOB_RXN12_EXTFB0); also elsewhere on the board
/CPU \ RAM/A13: J24.4, U21.71 (GPIOB_CLKP0); also elsewhere on the board
/CPU \ RAM/A14: J24.6, U21.76 (GPIOR_155); also elsewhere on the board
/CPU \ RAM/A15: J24.8, U21.77 (GPIOR_154); also elsewhere on the board
/CPU \ RAM/D0: J24.14, U21.87 (GPIOR_132_CDI19); also elsewhere on the board
/CPU \ RAM/D1: J24.16, U21.90 (GPIOR_128_CTRL11); also elsewhere on the board
/CPU \ RAM/D2: J24.18, U21.93 (GPIOR_123_CLK12_CDI20); also elsewhere on the board
/CPU \ RAM/D3: J24.20, U21.101 (GPIOR_112_CDI23); also elsewhere on the board
/CPU \ RAM/D4: J24.22, U21.103 (GPIOR_104_CDI25); also elsewhere on the board
/CPU \ RAM/D5: J24.24, U21.106 (GPIOR_94_CDI27); also elsewhere on the board
/CPU \ RAM/D6: J24.26, U21.110 (GPIOR_87_CDI29); also elsewhere on the board
/CPU \ RAM/D7: J24.28, U21.112 (GPIOR_86); also elsewhere on the board
/CPU \ RAM/RAM_A10: J24.23, U21.109 (GPIOR_88_CDI28); also elsewhere on the board
/CPU \ RAM/RAM_A11: J24.27, U21.113 (GPIOR_84); also elsewhere on the board
/CPU \ RAM/RAM_A15: J24.10, U21.82 (GPIOR_138); also elsewhere on the board
/CPU \ RAM/RAM_A16: J24.12, U21.84 (GPIOR_135_CDI17); also elsewhere on the board
/CPU \ RAM/~NMI: J21.22, U21.139 (GPIOL_68); also elsewhere on the board
/CPU \ RAM/~RES: J23.27, U21.98 (GPIOR_117_CTRL14); also elsewhere on the board
/MAGIC/FPGA/AUDIO: J23.5, U21.38 (GPIOB_TXP00); also elsewhere on the board
/MAGIC/FPGA/BE: J23.25, U21.67 (GPIOB_RXP10); also elsewhere on the board
/MAGIC/FPGA/CBUS0: RN15.3 (R3.1), U21.78 (GPIOR_151_CBUS0)
/MAGIC/FPGA/CBUS1: RN15.2 (R2.1), U21.79 (GPIOR_150_CBUS1)
/MAGIC/FPGA/CBUS2: RN15.1 (R1.1), U21.80 (GPIOR_149_CBUS2)
/MAGIC/FPGA/CDONE: J19.16, R30.2, RN14.4 (R4.1), U21.34 (CDONE)
/MAGIC/FPGA/CEC: J16.21, U21.4 (GPIOL_54_CDI11); also elsewhere on the board
/MAGIC/FPGA/CSI: R27.1, U21.32 (GPIOL_04_CSI)
/MAGIC/FPGA/DIAG: J23.15, U21.53 (GPIOB_TXP11); also elsewhere on the board
/MAGIC/FPGA/FPGA_CLK: J21.16, U21.132 (GPIOL_74_PLLIN0); also elsewhere on the board
/MAGIC/FPGA/FPGA_SPI0_TX: R70.2, U21.28 (GPIOL_09_CDI1)
/MAGIC/FPGA/FPGA_SPI1_TX: R68.2, U21.7 (GPIOL_41_CDI9)
/MAGIC/FPGA/FPGA_SPI1_~READY: R71.2, U21.14 (GPIOL_25_CLK1)
/MAGIC/FPGA/GRAPHICS: J23.17, U21.55 (GPIOB_RXP00); also elsewhere on the board
/MAGIC/FPGA/HOLD: J19.15
/MAGIC/FPGA/I2C1_SCL: J16.6, U21.15 (GPIOL_24_CLK0); also elsewhere on the board
/MAGIC/FPGA/I2C1_SDA: J16.4, U21.16 (GPIOL_22_CTRL2); also elsewhere on the board
/MAGIC/FPGA/L53: J21.25, U21.3 (GPIOL_53_CDI10)
/MAGIC/FPGA/L64: J21.26, U21.144 (GPIOL_64)
/MAGIC/FPGA/L65: J21.24, U21.141 (GPIOL_65)
/MAGIC/FPGA/L66: J21.23, U21.142 (GPIOL_66_CDI12)
/MAGIC/FPGA/L67: J21.21, U21.140 (GPIOL_67_CDI13)
/MAGIC/FPGA/L75: J21.11, U21.131 (GPIOL_75_PLLIN1)
/MAGIC/FPGA/N00: J23.6, U21.39 (GPIOB_TXN00)
/MAGIC/FPGA/N02: J23.8, U21.41 (GPIOB_TXN02)
/MAGIC/FPGA/N04: J23.10, U21.43 (GPIOB_TXN04)
/MAGIC/FPGA/N06: J23.12, U21.46 (GPIOB_TXN06)
/MAGIC/FPGA/N09: J23.14, U21.48 (GPIOB_TXN09)
/MAGIC/FPGA/NSTATUS: J19.11, J21.17, R31.2, U21.136 (GPIOL_71_NSTATUS)
/MAGIC/FPGA/P02: J23.7, U21.40 (GPIOB_TXP02)
/MAGIC/FPGA/P04: J23.9, U21.42 (GPIOB_TXP04)
/MAGIC/FPGA/P06: J23.11, U21.45 (GPIOB_TXP06)
/MAGIC/FPGA/P09: J23.13, U21.47 (GPIOB_TXP09)
/MAGIC/FPGA/R76: J21.12, U21.124 (GPIOR_76_PLLIN0)
/MAGIC/FPGA/RDY: J23.21, U21.60 (GPIOB_RXN03); also elsewhere on the board
/MAGIC/FPGA/REF_RES: R34.2, U21.36 (REF_RES)
/MAGIC/FPGA/S1: J21.15, SW5.8, U21.134 (GPIOL_73_EXTFB1_CDI15)
/MAGIC/FPGA/S2: J21.18, SW5.7, U21.135 (GPIOL_72_EXTFB0_CDI14)
/MAGIC/FPGA/S3: J21.20, SW5.6, U21.137 (GPIOL_70_CBSEL0)
/MAGIC/FPGA/S4: J21.19, SW5.5, U21.138 (GPIOL_69_CBSEL1)
/MAGIC/FPGA/SPI0_RX: J16.9, R70.1; also elsewhere on the board
/MAGIC/FPGA/SPI0_SCK: J16.5, U21.30 (GPIOL_01_CCK); also elsewhere on the board
/MAGIC/FPGA/SPI0_TX: J16.7, U21.29 (GPIOL_08_CDI0); also elsewhere on the board
/MAGIC/FPGA/SPI0_~CS: J16.3, J19.12, U21.31 (GPIOL_00_SS_N); also elsewhere on the board
/MAGIC/FPGA/SPI1_RX: J16.22, R68.1; also elsewhere on the board
/MAGIC/FPGA/SPI1_SCK: J16.18, U21.11 (GPIOL_31_CLK7_CDI6); also elsewhere on the board
/MAGIC/FPGA/SPI1_TX: J16.20, U21.8 (GPIOL_40_CDI8); also elsewhere on the board
/MAGIC/FPGA/SPI1_~CS: J16.16, U21.10 (GPIOL_32_CTRL4_CDI7); also elsewhere on the board
/MAGIC/FPGA/SPI1_~READY: J16.14, R71.1; also elsewhere on the board
/MAGIC/FPGA/SWCLK: J19.3; also elsewhere on the board
/MAGIC/FPGA/SWD: J19.5; also elsewhere on the board
/MAGIC/FPGA/SYNC: J23.26, U21.68 (GPIOB_RXN10); also elsewhere on the board
/MAGIC/FPGA/TCK: J19.2, RN14.1 (R1.1), U21.26 (TCK)
/MAGIC/FPGA/TDI: J19.4, RN14.2 (R2.1), U21.27 (TDI)
/MAGIC/FPGA/TDO: J19.6, U21.24 (TDO)
/MAGIC/FPGA/TMS: J19.8, RN14.3 (R3.1), U21.25 (TMS)
/MAGIC/FPGA/UART_RX: J19.7; also elsewhere on the board
/MAGIC/FPGA/UART_TX: J19.9; also elsewhere on the board
/MAGIC/FPGA/VIA_CB2: J23.16, U21.54 (GPIOB_TXN11); also elsewhere on the board
/MAGIC/FPGA/YY1: J16.10, U21.20 (GPIOL_12_CDI2)
/MAGIC/FPGA/YY2: J16.11, U21.19 (GPIOL_13_CDI3)
/MAGIC/FPGA/YY3: J16.12, U21.18 (GPIOL_20_CTRL0_CDI4)
/MAGIC/FPGA/YY4: J16.13, U21.17 (GPIOL_21_CTRL1_CDI5)
/MAGIC/FPGA/YY5: J16.15, U21.6 (GPIOL_46)
/MAGIC/FPGA/YY6: J16.8, U21.33 (GPIOL_05_CSO)
/MAGIC/FPGA/~CRESET: J19.14, R33.1, U21.35 (~CRESET); also elsewhere on the board
/MAGIC/FPGA/~IRQ: J23.23, U21.65 (GPIOB_RXN07); also elsewhere on the board
/MAGIC/FPGA/~ML: J23.24, U21.66 (GPIOB_RXP07); also elsewhere on the board
/MAGIC/FPGA/~RAM_OE: J23.18, U21.56 (GPIOB_RXN00); also elsewhere on the board
/MAGIC/FPGA/~RAM_WE: J23.19, U21.58 (GPIOB_RXP02); also elsewhere on the board
/MAGIC/FPGA/~SO: J23.22, U21.61 (GPIOB_RXP03); also elsewhere on the board
/MAGIC/FPGA/~SPI_ENA: J19.13; also elsewhere on the board
/MAGIC/FPGA/~TEST: RN15.4 (R4.1), U21.74 (GPIOR_158_TEST_N)
/MAGIC/FPGA/~VP: J23.20, U21.59 (GPIOB_RXN02); also elsewhere on the board
/MAGIC/HORIZ: J21.8, U21.118 (GPIOR_79_EXTFB1_CDI30); also elsewhere on the board
/MAGIC/MCU/I2C0_SCL: J16.19; also elsewhere on the board
/MAGIC/MCU/I2C0_SDA: J16.17; also elsewhere on the board
/MAGIC/R~W: J24.30, U21.99 (GPIOR_116_CTRL15); also elsewhere on the board
/MAGIC/VERT: J21.6, U21.116 (GPIOR_81_MREFCLK); also elsewhere on the board
/MAGIC/VIDEO: J21.4, U21.114 (GPIOR_83); also elsewhere on the board
/MAGIC/~IO_OE: J21.10, U21.119 (GPIOR_78_EXTFB0_CDI31); also elsewhere on the board
/MAGIC/~PIA1_CS: J21.5, U21.115 (GPIOR_82); also elsewhere on the board
/MAGIC/~PIA2_CS: J21.9, U21.123 (GPIOR_77_PLLIN1); also elsewhere on the board
/MAGIC/~VIA_CS: J21.7, U21.117 (GPIOR_80); also elsewhere on the board
/MAGIC/ϕ2: J21.3, U21.97 (GPIOR_122_CLK13_CDI21); also elsewhere on the board
FPGA_VCCA: U21.2 (VCCA_TL), U21.73 (VCCA_BR), U21.107 (VCCA_TR); also elsewhere on the board
GND: C60.2, C61.2, C62.2, C63.2, C64.2, C65.2, C66.2, C67.2, C68.2, C69.2, C71.2, C72.2, C73.2, C75.2, C76.2, C77.2, C78.2, C79.2, C80.2, D9.1 (K), J16.1, J16.23, J19.1, J21.1, J21.2, J21.13, J21.14, J21.27, J21.28, J23.1, J23.2, J23.28, Q4.2 (E), R33.2, R34.1, SW5.1, SW5.2, SW5.3, SW5.4, U21.1 (GND), U21.5 (GND), U21.9 (GND), U21.37 (GND), U21.44 (GND), U21.50 (GND), U21.64 (GND), U21.94 (GND), U21.104 (GND), U21.108 (GND), U21.120 (GND), U21.121 (GND), U21.126 (GND), U21.127 (GND), U21.129 (GND), U21.133 (GND); also elsewhere on the board
unnamed: D8.1 (K), Q4.3 (C)
unnamed: D8.2 (A), R29.1
unnamed: D9.2 (A), R31.1
unnamed: Q4.1 (B), R30.1

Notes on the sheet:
During configuration, all GPIO pins excluding LVDS as GPIO are configured in weak pull-up mode. The LVDS as GPIO pins are tri-stated without a pull-up or pull-down resistor.
BD0
BD2
BD1
NSTATUS driven low on error
AD7
AD4
Pull ~{CRESET} low to reset FPGA until MCU is ready. Note that MCU drives ~{CRESET} through 10k resistor so it can be overridden by programmer when connected. Pull CSI high to enable FPGA configuration Pull TEST_N high to deactivate test mode Pull CBUS[2:0] high for SPI x1 Leave CBSEL[1:0] floating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
BD3
Minimum decoupling caps is one 100nF and one 10nF
AD5
AD6
AD3
CDONE is open drain and requires pullup to enter user mode. TDO is terminated by the programmer at the receiving end.
CDONE is an open drain output with 10k pullup. Driving LED requires a current amplifier.
Do not connect I2C0 to FPGA as it can be pulled up to +5V. (See MCU/DVI)

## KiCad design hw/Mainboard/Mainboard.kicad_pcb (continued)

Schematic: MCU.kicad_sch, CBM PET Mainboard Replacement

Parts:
C34: 10u; C_0603_1608Metric; LCSC C96446
C37, C38: 2.2u 6.3V; C_0402_1005Metric; LCSC C12530
C39, C40, C41, C42, C43, C44, C45, C46: 100n; C_0402_1005Metric; LCSC C1525
C47, C48: 30p; C_0402_1005Metric; LCSC C1570
C52: 1u; C_0402_1005Metric; LCSC C52923
D10: LED_GRN; LED_0603_1608Metric; LCSC C72043
J22: MENU; PinHeader_1x02_P2.54mm_Vertical
PT1, PT2: PowerTie_2; NetTie-2_SMD_Pad_0.4_to_0.2mm
R12, R15: 27; R_0603_1608Metric; LCSC C25190
R17, R23, R66: 1k; R_0402_1005Metric; LCSC C11702
R18, R24: 10k; R_0402_1005Metric; LCSC C25744
R19, R21, R22, R48, R51, R63, R67: 33; R_0402_1005Metric; LCSC C25105
R64, R65: 2k2; R_0402_1005Metric; LCSC C25879
SW2: RUN; SW-TH_L6.0-W3.5-P6.50
SW3: MENU; KEY-TH_SKHLLBA010
U14: RP2040; LQFN-56_L7.0-W7.0-P0.4-EP; LCSC C2040
Y1: 12 MHz; Crystal_SMD_3225-4Pin_3.2x2.5mm; LCSC C9002

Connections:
+3V3: PT1.1, R24.1, R64.1, R65.1; also elsewhere on the board
/MAGIC/FPGA/CEC: U14.36 (GPIO24); also elsewhere on the board
/MAGIC/FPGA/FPGA_CLK: R21.1; also elsewhere on the board
/MAGIC/FPGA/I2C1_SCL: R65.2, U14.5 (GPIO3); also elsewhere on the board
/MAGIC/FPGA/I2C1_SDA: R64.2, U14.4 (GPIO2); also elsewhere on the board
/MAGIC/FPGA/SPI0_RX: U14.6 (GPIO4); also elsewhere on the board
/MAGIC/FPGA/SPI0_SCK: R19.1; also elsewhere on the board
/MAGIC/FPGA/SPI0_TX: R67.1; also elsewhere on the board
/MAGIC/FPGA/SPI0_~CS: R63.1; also elsewhere on the board
/MAGIC/FPGA/SPI1_RX: U14.15 (GPIO12); also elsewhere on the board
/MAGIC/FPGA/SPI1_SCK: R22.1; also elsewhere on the board
/MAGIC/FPGA/SPI1_TX: R48.1; also elsewhere on the board
/MAGIC/FPGA/SPI1_~CS: R51.1; also elsewhere on the board
/MAGIC/FPGA/SPI1_~READY: U14.13 (GPIO10); also elsewhere on the board
/MAGIC/FPGA/SWCLK: U14.24 (SWCLK); also elsewhere on the board
/MAGIC/FPGA/SWD: U14.25 (SWD); also elsewhere on the board
/MAGIC/FPGA/UART_RX: U14.3 (GPIO1); also elsewhere on the board
/MAGIC/FPGA/UART_TX: U14.2 (GPIO0); also elsewhere on the board
/MAGIC/FPGA/~CRESET: R18.2; also elsewhere on the board
/MAGIC/FPGA/~SPI_ENA: R66.1; also elsewhere on the board
/MAGIC/MCU/DVDD: C37.1, C39.1, C40.1, U14.23 (DVDD), U14.45 (VREG_VOUT), U14.50 (DVDD)
/MAGIC/MCU/DVI/DVI_CK+: U14.28 (GPIO17); also elsewhere on the board
/MAGIC/MCU/DVI/DVI_CK-: U14.27 (GPIO16); also elsewhere on the board
/MAGIC/MCU/DVI/DVI_D0+: U14.30 (GPIO19); also elsewhere on the board
/MAGIC/MCU/DVI/DVI_D0-: U14.29 (GPIO18); also elsewhere on the board
/MAGIC/MCU/DVI/DVI_D1+: U14.32 (GPIO21); also elsewhere on the board
/MAGIC/MCU/DVI/DVI_D1-: U14.31 (GPIO20); also elsewhere on the board
/MAGIC/MCU/DVI/DVI_D2+: U14.35 (GPIO23); also elsewhere on the board
/MAGIC/MCU/DVI/DVI_D2-: U14.34 (GPIO22); also elsewhere on the board
/MAGIC/MCU/Flash/SCK: U14.52 (QSPI_SCLK); also elsewhere on the board
/MAGIC/MCU/Flash/SD0: U14.53 (QSPI_SD0); also elsewhere on the board
/MAGIC/MCU/Flash/SD1: U14.55 (QSPI_SD1); also elsewhere on the board
/MAGIC/MCU/Flash/SD2: U14.54 (QSPI_SD2); also elsewhere on the board
/MAGIC/MCU/Flash/SD3: U14.51 (QSPI_SD3); also elsewhere on the board
/MAGIC/MCU/Flash/~CS: U14.56 (QSPI_SS); also elsewhere on the board
/MAGIC/MCU/GP25: R23.1, U14.37 (GPIO25)
/MAGIC/MCU/GP27: C52.1, J22.2, SW3.1, U14.39 (GPIO27_ADC1)
/MAGIC/MCU/I2C0_SCL: U14.41 (GPIO29_ADC3); also elsewhere on the board
/MAGIC/MCU/I2C0_SDA: U14.40 (GPIO28_ADC2); also elsewhere on the board
/MAGIC/MCU/MCU_FPGA_CLK: R21.2, U14.18 (GPIO15)
/MAGIC/MCU/MCU_SPI0_SCK: R19.2, U14.8 (GPIO6)
/MAGIC/MCU/MCU_SPI0_TX: R67.2, U14.9 (GPIO7)
/MAGIC/MCU/MCU_SPI0_~CS: R63.2, U14.7 (GPIO5)
/MAGIC/MCU/MCU_SPI1_SCK: R22.2, U14.17 (GPIO14)
/MAGIC/MCU/MCU_SPI1_TX: R48.2, U14.14 (GPIO11)
/MAGIC/MCU/MCU_SPI1_~CS: R51.2, U14.16 (GPIO13)
/MAGIC/MCU/MCU_TESTEN: PT2.2, U14.19 (TESTEN)
/MAGIC/MCU/MCU_USB_D+: R12.1, U14.47 (USB_DP)
/MAGIC/MCU/MCU_USB_D-: R15.1, U14.46 (USB_DM)
/MAGIC/MCU/MCU_~CRESET: R18.1, U14.38 (GPIO26_ADC0)
/MAGIC/MCU/RUN: C34.1, R24.2, R66.2, SW2.2, U14.26 (RUN)
/MAGIC/MCU/SD_DETECT: U14.11 (GPIO8); also elsewhere on the board
/MAGIC/MCU/SD_~CS: U14.12 (GPIO9); also elsewhere on the board
/MAGIC/MCU/USB/USB_D+: R12.2; also elsewhere on the board
/MAGIC/MCU/USB/USB_D-: R15.2; also elsewhere on the board
/MAGIC/MCU/XIN: C47.2, U14.20 (XIN), Y1.1
/MAGIC/MCU/XOUT: R17.2, U14.21 (XOUT)
GND: C34.2, C37.2, C38.2, C39.2, C40.2, C41.2, C42.2, C43.2, C44.2, C45.2, C46.2, C47.1, C48.1, C52.2, D10.1 (K), J22.1, PT2.1, SW3.2, U14.57 (GND), Y1.2, Y1.4; also elsewhere on the board
MCU_IOVDD: C38.1, C41.1, C42.1, C43.1, C44.1, C45.1, C46.1, PT1.2, U14.1 (IOVDD), U14.10 (IOVDD), U14.22 (IOVDD), U14.33 (IOVDD), U14.42 (IOVDD), U14.43 (ADC_AVDD), U14.44 (VREG_IN), U14.48 (USB_VDD), U14.49 (IOVDD)
unnamed: C48.2, R17.1, Y1.3
unnamed: D10.2 (A), R23.2
PD_GND: SW2.1; also elsewhere on the board

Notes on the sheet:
IO/USB/AVDD Decoupling
~{SPI_ENA} is driven low during FPGA programming. We use this to hold the MCU in reset when updating the FPGA to avoid contention on SPI pins. FT2232H can source/sink ~8ma, so 1K should be ok.
DVDD Decoupling
10k resistor on ~{CRESET} enables programmer to override MCU during development.

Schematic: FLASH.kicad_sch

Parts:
C51: 100n; C_0402_1005Metric; LCSC C1525
J17: BOOTSEL; PinHeader_1x02_P2.54mm_Vertical
R25: 10k; R_0402_1005Metric; LCSC C25744
R26: 1k; R_0402_1005Metric; LCSC C11702
U16: W25Q128JVS; SOIC-8_5.23x5.23mm_P1.27mm; LCSC C97521

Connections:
+3V3: C51.1, R25.1, U16.8 (VCC); also elsewhere on the board
/MAGIC/MCU/Flash/BOOTSEL: J17.2, R26.1
/MAGIC/MCU/Flash/SCK: U16.6 (CLK); also elsewhere on the board
/MAGIC/MCU/Flash/SD0: U16.5 (DI(IO0)); also elsewhere on the board
/MAGIC/MCU/Flash/SD1: U16.2 (DO(IO1)); also elsewhere on the board
/MAGIC/MCU/Flash/SD2: U16.3 (IO2); also elsewhere on the board
/MAGIC/MCU/Flash/SD3: U16.7 (IO3); also elsewhere on the board
/MAGIC/MCU/Flash/~CS: R25.2, R26.2, U16.1 (~CS); also elsewhere on the board
GND: C51.2, J17.1, U16.4 (GND); also elsewhere on the board

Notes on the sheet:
Flash

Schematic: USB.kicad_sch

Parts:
J14: USB2.0_HOST_TYPE_C; USB-C_SMD-TYPE-C-31-M-12; LCSC C165948
PT10, PT11, PT19, PT20: PowerTie_2; NetTie-2_SMD_Pad_1.6_to_0.4mm
R35, R36: 56k; R_0402_1005Metric; LCSC C25796

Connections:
+5V: PT19.1, PT20.1; also elsewhere on the board
/MAGIC/MCU/USB/CC1: J14.A5 (CC1), R35.2
/MAGIC/MCU/USB/CC2: J14.B5 (CC2), R36.2
/MAGIC/MCU/USB/USB_D+: J14.A6 (D+), J14.B6 (D+); also elsewhere on the board
/MAGIC/MCU/USB/USB_D-: J14.A7 (D-), J14.B7 (D-); also elsewhere on the board
GND: J14.S1 (SHIELD); also elsewhere on the board
unnamed: J14.A1_B12 (GND), PT11.2
unnamed: J14.A4_B9 (VBUS), PT19.2, R35.1
unnamed: J14.A9_B4 (VBUS), PT20.2, R36.1
unnamed: J14.A12_B1 (GND), PT10.2
PD_GND: PT10.1, PT11.1; also elsewhere on the board

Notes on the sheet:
USB 2.0 Host over USB-C connector 56k pullups on CC1 and CC2 identify USB-C as a downstream facing port (DFP) supplying up to 900ma @ 5V.
USB

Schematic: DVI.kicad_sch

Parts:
J12: NOT_HDMI_A; HDMI_A_Molex_208658-1001_Horizontal; LCSC C138388
JP7: DVI_CEC; SolderJumper-2_P1.3mm_Open_RoundedPad1.0x1.5mm
JP8: DVI_SCL; SolderJumper-2_P1.3mm_Open_RoundedPad1.0x1.5mm
JP9: DVI_SDA; SolderJumper-2_P1.3mm_Open_RoundedPad1.0x1.5mm
PT18: PowerTie_2; NetTie-2_SMD_Pad_1.6_to_0.4mm
R1, R2, R3, R4, R5, R6, R10, R11, R16: 270; R_0603_1608Metric; LCSC C22966
R7, R8, R9: 2k2; R_0402_1005Metric; LCSC C25879

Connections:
+3V3: R7.1; also elsewhere on the board
+5V: PT18.1; also elsewhere on the board
/MAGIC/FPGA/CEC: JP7.1 (A); also elsewhere on the board
/MAGIC/MCU/DVI/DVI_CK+: R10.1; also elsewhere on the board
/MAGIC/MCU/DVI/DVI_CK-: R11.1; also elsewhere on the board
/MAGIC/MCU/DVI/DVI_D0+: R5.1; also elsewhere on the board
/MAGIC/MCU/DVI/DVI_D0-: R6.1; also elsewhere on the board
/MAGIC/MCU/DVI/DVI_D1+: R3.1; also elsewhere on the board
/MAGIC/MCU/DVI/DVI_D1-: R4.1; also elsewhere on the board
/MAGIC/MCU/DVI/DVI_D2+: R1.1; also elsewhere on the board
/MAGIC/MCU/DVI/DVI_D2-: R2.1; also elsewhere on the board
/MAGIC/MCU/DVI/HDMI_CEC: J12.13 (CEC), R16.2
/MAGIC/MCU/DVI/HDMI_CK+: J12.10 (CK+), R10.2
/MAGIC/MCU/DVI/HDMI_CK-: J12.12 (CK-), R11.2
/MAGIC/MCU/DVI/HDMI_D0+: J12.7 (D0+), R5.2
/MAGIC/MCU/DVI/HDMI_D0-: J12.9 (D0-), R6.2
/MAGIC/MCU/DVI/HDMI_D1+: J12.4 (D1+), R3.2
/MAGIC/MCU/DVI/HDMI_D1-: J12.6 (D1-), R4.2
/MAGIC/MCU/DVI/HDMI_D2+: J12.1 (D2+), R1.2
/MAGIC/MCU/DVI/HDMI_D2-: J12.3 (D2-), R2.2
/MAGIC/MCU/DVI/HDMI_SCL: J12.15 (SCL), JP8.2 (B), R8.2
/MAGIC/MCU/DVI/HDMI_SDA: J12.16 (SDA), JP9.2 (B), R9.2
/MAGIC/MCU/I2C0_SCL: JP8.1 (A); also elsewhere on the board
/MAGIC/MCU/I2C0_SDA: JP9.1 (A); also elsewhere on the board
GND: J12.2 (D2S), J12.5 (D1S), J12.8 (D0S), J12.11 (CKS), J12.17 (GND), J12.SH; also elsewhere on the board
unnamed: J12.18 (+5V), PT18.2, R8.1, R9.1
unnamed: JP7.2 (B), R7.2, R16.1

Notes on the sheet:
NOT
CEC and I2C are for possible future use. DANGER: Closing the SCL/SDA jumpers pulls the corresponding GPIO pins to +5V. Only do this if you know what you're doing.

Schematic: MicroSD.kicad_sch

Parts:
C49: 100n; C_0402_1005Metric; LCSC C1525
C50: 10u 6.3V; C_0402_1005Metric; LCSC C15525
J13: MicroSD; TF-SMD_TF-PUSH; LCSC C393941
R20: 10k; R_0402_1005Metric; LCSC C25744
R69: 33; R_0402_1005Metric; LCSC C25105
RN16: 10k; R_Array_Convex_4x0603; LCSC C29718

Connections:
+3V3: C49.1, C50.1, J13.4 (VDD), R20.1, RN16.5 (R4.2), RN16.6 (R3.2), RN16.7 (R2.2), RN16.8 (R1.2); also elsewhere on the board
/MAGIC/FPGA/SPI0_RX: R69.2, RN16.4 (R4.1); also elsewhere on the board
/MAGIC/FPGA/SPI0_SCK: J13.5 (CLK); also elsewhere on the board
/MAGIC/FPGA/SPI0_TX: J13.3 (CMD), RN16.3 (R3.1); also elsewhere on the board
/MAGIC/MCU/SD_DETECT: J13.9 (DET); also elsewhere on the board
/MAGIC/MCU/SD_~CS: J13.2 (DAT3/CD), RN16.2 (R2.1); also elsewhere on the board
GND: C49.2, C50.2, J13.6 (VSS), J13.10 (SHIELD), J13.11 (SHIELD), J13.12 (SHIELD), J13.13 (SHIELD); also elsewhere on the board
unnamed: J13.1 (DAT2), RN16.1 (R1.1)
unnamed: J13.7 (DAT0), R69.1
unnamed: J13.8 (DAT1), R20.2

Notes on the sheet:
DAT[0] : (POCI) is open-drain output that requires pullup. DAT[2:1] : Unused inputs in SPI mode. Pullups recommended to avoid current draw due to metastablitiy. DAT[3] : (~{CS}) has built-in 22-50k pullup to ensure card is deselected by default. CMD : (PICO) input in SPI mode. CLK : (SCK) always an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
MicroSD

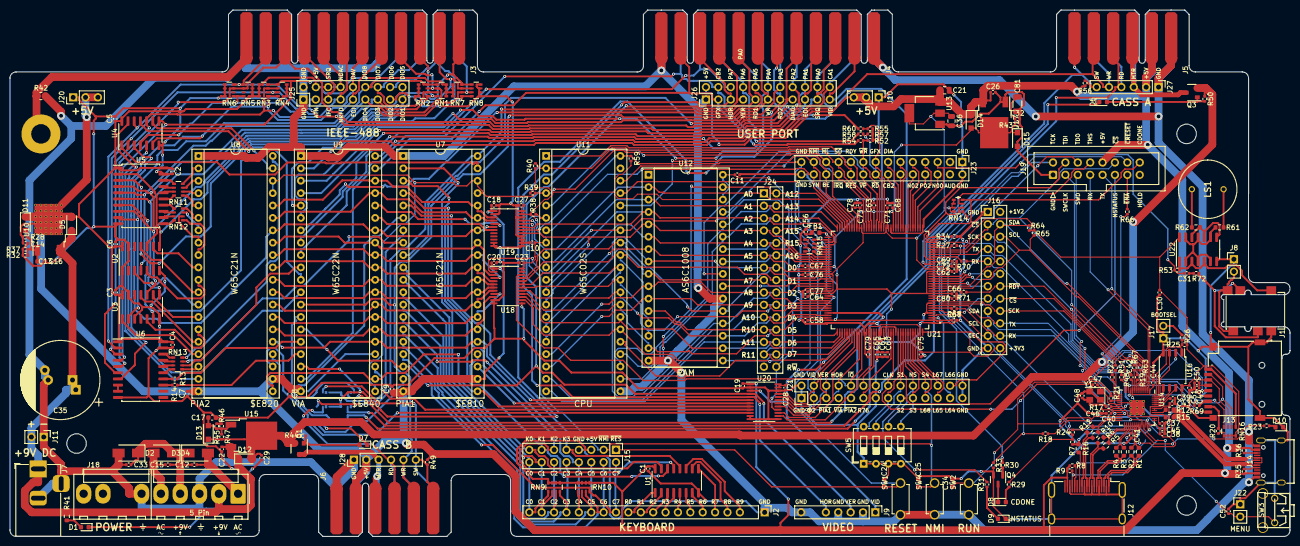
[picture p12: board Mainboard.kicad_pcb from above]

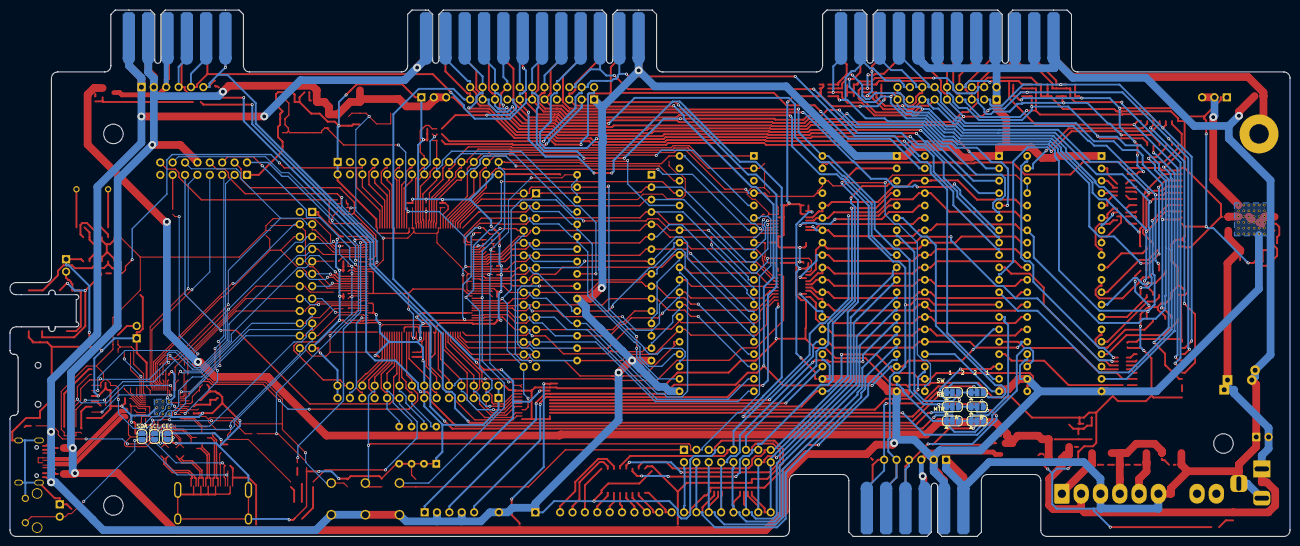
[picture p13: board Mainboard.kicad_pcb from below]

Board: 2 copper layers, 262.5 x 107.9 mm, 285 parts (15 on the bottom side), 356 nets.

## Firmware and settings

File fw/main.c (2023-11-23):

/**
 * PET Clone - Open hardware implementation of the Commodore PET
 * by Daniel Lehenbauer and contributors.
 * 
 * https://github.com/DLehenbauer/commodore-pet-clone
 *
 * To the extent possible under law, I, Daniel Lehenbauer, have waived all
 * copyright and related or neighboring rights to this project. This work is
 * published from the United States.
 *
 * @copyright CC0 http://creativecommons.org/publicdomain/zero/1.0/
 * @author Daniel Lehenbauer <DLehenbauer@users.noreply.github.com> and contributors
 */

// #define TEST

#include "pch.h"
#include "driver.h"
#include "dvi/dvi.h"
#include "global.h"
#include "sd/sd.h"
#include "fpga/fpga.h"

#ifdef TEST
#include "test.h"
#else
#include "pet.h"
#endif

#include "usb/usb.h"

void init() {
    // Turn on LED at start of config to signal that the RP2040 has booted and FPGA
    // configuration has started.  (Note that 'usb_init()' will turn the LED off.)
    const uint led_pin = PICO_DEFAULT_LED_PIN;
    gpio_init(led_pin);
    gpio_set_dir(led_pin, GPIO_OUT);
    gpio_put(led_pin, 1);

    fpga_init();
    fpga_config();
    printf("FPGA initialized.\n");
    driver_init();
    printf("Driver initialized.\n");
    init_sd();
    printf("SD initialized.\n");
    usb_init();
    printf("USB initialized.\n");
    video_init();
    printf("Video initialized.\n");
}

int main() {
    init();

#ifdef TEST
    test_ram();
    // test_display();
#else
    pet_reset();
    printf("PET reset.\n");
    pet_main();
#endif

    __builtin_unreachable();
}

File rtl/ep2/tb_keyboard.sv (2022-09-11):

`timescale 1ns / 1ps

/**
 * PET Clone - Open hardware implementation of the Commodore PET
 * by Daniel Lehenbauer and contributors.
 * 
 * https://github.com/DLehenbauer/commodore-pet-clone
 *
 * To the extent possible under law, I, Daniel Lehenbauer, have waived all
 * copyright and related or neighboring rights to this project. This work is
 * published from the United States.
 *
 * @copyright CC0 http://creativecommons.org/publicdomain/zero/1.0/
 * @author Daniel Lehenbauer <DLehenbauer@users.noreply.github.com> and contributors
 */

module tb();
    localparam PORTA = 2'd0,
               PORTB = 2'd2;

    reg [15:0] pi_addr  = 16'hxxxx;
    reg [7:0]  pi_data  = 8'hxx;
    reg        pi_write = 0;

    reg [1:0]  bus_addr    = 2'h0;
    reg [7:0]  bus_data_in = 8'h0;
    reg        bus_rw_b    = 0;

    reg io_select = 0;
    reg pia1_enabled_in = 0;
    reg cpu_write = 0;

    wire kbd_enable;
    wire [7:0] kbd_data_out;

    wire io_read = io_select && bus_rw_b;

    keyboard keyboard(
        .pi_addr(pi_addr),
        .pi_data(pi_data),
        .pi_write(pi_write),

        .bus_addr(bus_addr),
        .bus_data_in(bus_data_in),
        .bus_rw_b(bus_rw_b),

        .io_read(io_read),
        .cpu_write(cpu_write),
        .pia1_enabled_in(pia1_enabled_in),

        .kbd_data_out(kbd_data_out),
        .kbd_enable(kbd_enable)
    );

    task check(
        input expected_kbd_enable,
        input [7:0] expected_kbd_data_out
    );
        $display("[%t] CHECK %d %d", $time, kbd_enable, kbd_data_out);
        assert_equal(kbd_enable, expected_kbd_enable, "kbd_enable");
        assert_equal(kbd_data_out, expected_kbd_data_out, "kbd_data_out");
    endtask

    task set_key_row(
        input [9:0] row,
        input [7:0] value
    );
        pi_addr = 16'he800 + row;
        pi_data = value;
        
        #1;
        
        pi_write = 1;

        #1;
        
        pi_write = 0;
        
        #1;
        pi_addr = 16'hxxxx;
        pi_data = 8'hxx;
    endtask

    task read_key_row(
        input [3:0] row,
        input [7:0] expected_col
    );
        bus_addr = PORTA;
        bus_data_in = row;
        bus_rw_b = 1'b0;

        #1;

        io_select = 1;
        pia1_enabled_in = 1;

        #1;

        cpu_write = 1;

        #1;

        cpu_write = 0;

        #1;

        io_select = 0;
        pia1_enabled_in = 0;

        #1;

        bus_addr = PORTB;
        bus_data_in = 8'hxx;
        bus_rw_b = 1;

        #1; 

        io_select = 1;
        pia1_enabled_in = 1;

        #1;

        assert_equal(kbd_enable, 1, "kbd_enable");
        assert_equal(kbd_data_out, expected_col, "kbd_data_out");

        #1;

        io_select = 0;
        pia1_enabled_in = 0;

        #1;

        bus_addr = 2'bxx;
        bus_rw_b = 1'bx;

        #1;
    endtask

    initial begin
        integer row;
        integer col;

        $dumpfile("out.vcd");
        $dumpvars;

        col = 1;

        for (row = 0; row < 10; row++) begin
            #1 $display("[%t] Test: Pi sets row %d to %d", $time, row, col);

            set_key_row(row, col);
            read_key_row(row, col);

            col = (col << 1);
            if (col > 8'hff) col = 1;
        end

        $display("[%t] Test Complete", $time);
        $finish;
    end
endmodule

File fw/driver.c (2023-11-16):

/**
 * PET Clone - Open hardware implementation of the Commodore PET
 * by Daniel Lehenbauer and contributors.
 * 
 * https://github.com/DLehenbauer/commodore-pet-clone
 *
 * To the extent possible under law, I, Daniel Lehenbauer, have waived all
 * copyright and related or neighboring rights to this project. This work is
 * published from the United States.
 *
 * @copyright CC0 http://creativecommons.org/publicdomain/zero/1.0/
 * @author Daniel Lehenbauer <DLehenbauer@users.noreply.github.com> and contributors
 */

#include "driver.h"
#include "hw.h"

#define SPI_CMD_READ_AT    0xC0
#define SPI_CMD_READ_NEXT  0x80
#define SPI_CMD_WRITE_AT   0x40
#define SPI_CMD_WRITE_NEXT 0x00

void driver_init() {
    // Configure SPI_CS_N_PIN as GPIO_OUT rather than GPIO_FUNC_SPI because the RP2040's
    // hardware CS_N deasserts between bytes and our design relies on CS_N being held low
    // to frame multibyte commands transmitted to the FPGA.
    //
    // (See https://github.com/raspberrypi/pico-sdk/issues/88)

    gpio_init(SPI_CSN_PIN);
    gpio_set_dir(SPI_CSN_PIN, GPIO_OUT);
    gpio_put(SPI_CSN_PIN, 1);

    // In case the MCU is reset mid-transmission, Hold CS_N high long enough to trigger a
    // synchronous reset of the FPGA's state machine so it is ready for a new command.
    sleep_ms(1);
    
    gpio_init(SPI_READY_B_PIN);
    gpio_set_dir(SPI_READY_B_PIN, GPIO_IN);

    uint baudrate = spi_init(SPI_INSTANCE, SPI_MHZ * 1000 * 1000);
    gpio_set_function(SPI_SCK_PIN, GPIO_FUNC_SPI);
    gpio_set_function(SPI_TX_PIN, GPIO_FUNC_SPI);
    gpio_set_function(SPI_RX_PIN, GPIO_FUNC_SPI);

    printf("    spi1     = %d Bd\n", baudrate);
}

void cmd_start() {
    while (!gpio_get(SPI_READY_B_PIN));
    gpio_put(SPI_CSN_PIN, 0);
}

void cmd_end() {
    while (gpio_get(SPI_READY_B_PIN));
    gpio_put(SPI_CSN_PIN, 1);
}

uint8_t spi_read_at(uint32_t addr) {
    const uint8_t cmd = SPI_CMD_READ_AT | addr >> 16;
    const uint8_t addr_hi = addr >> 8;
    const uint8_t addr_lo = addr & 0xff;
    const uint8_t tx[] = { cmd, addr_hi, addr_lo };

    cmd_start();
    spi_write_blocking(SPI_INSTANCE, tx, sizeof(tx));
    cmd_end();
}

uint8_t spi_read_next() {
    const uint8_t tx[1] = { SPI_CMD_READ_NEXT };
    uint8_t rx[sizeof(tx)];

    cmd_start();
    spi_write_read_blocking(SPI_INSTANCE, tx, rx, sizeof(tx));
    cmd_end();
    
    return rx[0];
}

void spi_read(uint8_t* pDest, uint32_t src, uint32_t byteLength) {
    spi_read_at(src);

    while (byteLength--) {
        *pDest++ = spi_read_next();
    }
}

void spi_write_at(uint32_t addr, uint8_t data) {
    const uint8_t cmd = SPI_CMD_WRITE_AT | addr >> 16;
    const uint8_t addr_hi = addr >> 8;
    const uint8_t addr_lo = addr & 0xff;
    const uint8_t tx [] = { cmd, data, addr_hi, addr_lo };

    cmd_start();
    spi_write_blocking(SPI_INSTANCE, tx, sizeof(tx));
    cmd_end();
}

void spi_write_next(uint8_t data) {
    const uint8_t tx [] = { SPI_CMD_WRITE_NEXT, data };

    cmd_start();
    spi_write_blocking(SPI_INSTANCE, tx, sizeof(tx));
    cmd_end();
}

void spi_write(uint32_t dest, const uint8_t const* pSrc, uint32_t byteLength) {
    const uint8_t* p = pSrc;
    
    if (byteLength--) {
        spi_write_at(dest, *p++);

        while (byteLength--) {
            spi_write_next(*p++);
        }
    }
}

void set_cpu(bool reset, bool run) {
    spi_write_at(0xE80F,
        (reset ? 0 : (1 << 0))          // res_b
        | (run ? (1 << 1) : 0));        // rdy
    
    sleep_ms(1);
}

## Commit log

2022-06-11 Init: WIP
    [Audio.kicad_sch, CASS.kicad_sch, CPU.kicad_sch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]
2022-06-17 wip: pre-routing
    [CPU.kicad_sch, IEEE.kicad_sch, MAGIC.kicad_sch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]
2022-06-18 wip: decent routing, remove run btn
    [CASS.kicad_sch, CPU.kicad_sch, IEEE.kicad_sch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]
2022-06-19 gnd/+5v on unused resistors to improve routing
    [CASS.kicad_sch, CPU.kicad_sch, IEEE.kicad_sch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]
2022-06-29 Sch: Note pull ups
    [MAGIC.kicad_sch]
2022-08-20 sw: remove dead code from driver.cpp
2022-08-20 hw: 160uF filtering, layout and silk tweaks
    [CASS.kicad_sch, MAGIC.kicad_sch, Mainboard.kicad_sch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]
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2022-08-20 schematics: link to raw image
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2022-08-20 hw: small layout adjustments
    [IEEE.kicad_sch]
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2022-09-13 Document schematics
    [Audio.kicad_sch, CASS.kicad_sch, CPU.kicad_sch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]
2022-09-14 hw: more schematic comments / cleanup
    [CASS.kicad_sch, CPU.kicad_sch, IEEE.kicad_sch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]
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2022-09-17 crtc: res_b -> reset
    [crtc.sv]
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2022-09-21 wip: possible spi_bridge fix
    [spi_bridge.sv]
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2022-10-11 wip: avoid using byte_valid as clk
    [spi_bridge.sv]
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2022-11-06 crtc: missing bit in R12
    [crtc.sv]
2022-11-10 Fix a couple benign warnings
    [spi_bridge.sv]
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2022-11-21 rtl: Fix warning about P9/D5 being tri-stated
    [spi_bridge.sv]
2022-11-23 rtl: remove reset alias from spi_bridge
    [spi_bridge.sv]
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2022-11-24 Revert "rtl: move spi_ready_no negation into spi_bridge"
    This reverts commit 6c3ece49607a4107aeb7ab5cf6bbce34afeb89f2.
    [spi_bridge.sv]
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2022-11-28 rtl: fix lower-case (use clk8n to capture spi)
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2022-12-16 hw: fix disconnection in schematic
    [Audio.kicad_sch, CASS.kicad_sch, CPU.kicad_sch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]
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2022-12-26 hw: whitespace
    [Audio.kicad_sch, CASS.kicad_sch, CPU.kicad_sch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]
2022-12-26 hw: wip add MCU, 2 layer board
    [CASS.kicad_sch, IEEE.kicad_sch, IO.kicad_sch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]
2022-12-28 hw: T8 (wip)
    [Audio.kicad_sch, CPU.kicad_sch, FPGA_CFG.kicad_sch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]
2023-01-01 hw: routing (excluding MCU)
    [Audio.kicad_sch, CPU.kicad_sch, MAGIC.kicad_sch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]
2023-01-04 hw: routed, but trace sizes need to be reviewed/fixed
    [CASS.kicad_sch, Keyboard.kicad_sch, MAGIC.kicad_sch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]
2023-01-07 hw: routable (wip)
    [Audio.kicad_sch, CASS.kicad_sch, CPU.kicad_sch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]
2023-01-08 hw: wip
    [Keyboard.kicad_sch, MAGIC.kicad_sch, MCU.kicad_sch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]
2023-01-09 hw: pull cbus0 high
    [MAGIC.kicad_sch, MCU.kicad_sch, Mainboard.kicad_pcb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]
2023-01-15 hw: larger schematic pages, routed w/netties
    [Audio.kicad_sch, CASS.kicad_sch, CPU.kicad_sch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]
2023-01-16 hw: indent copper fill
    [Mainboard.kicad_pcb]
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2023-01-21 jlcpcb - 1/19
    [Audio.kicad_sch, CASS.kicad_sch, CPU.kicad_sch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]
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2023-01-23 hw: drive CRESET through 10k, remove TDO pullup
    [MCU.kicad_sch, Mainboard.kicad_sch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]
2023-01-23 hw: RDY should be series resistor instead of pullup
    [CPU.kicad_sch]
2023-01-23 hw: 10uF -> 22uF smoothing caps
    [Mainboard.kicad_sch, POWER.kicad_sch]
2023-01-29 hw: minor routing tweaks
    [MAGIC.kicad_sch]
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2023-02-06 hw: pin 1 of 50 MHz oscillator can float
    [CPLD.kicad_sch]
2023-02-21 wip: fw: init CSN pin and rom.h tweak
2023-02-22 wip: fw: target Pico SDK 1.5 (rm 'rpi' from docker)
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2023-03-20 hw: rename 'CPLD' sheet to 'FPGA'
    [FPGA.kicad_sch, MAGIC.kicad_sch]
2023-03-20 hw: remove 50 MHz oscillator
    [FPGA.kicad_sch, Mainboard.kicad_sch]
2023-03-20 hw: use LM317 for +5V
    [Mainboard.kicad_sch, POWER.kicad_sch]
2023-03-20 hw: fix reversed signal and chassis gnd on IEEE
    [IEEE.kicad_sch]
2023-03-22 hw: tidy power and resize pages
    [Audio.kicad_sch, CASS.kicad_sch, CPU.kicad_sch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]
2023-03-22 hw: tidy CPU, rename RD/WR strobe to RAM_OE/_WE, debounce switches
    [CPU.kicad_sch, FPGA.kicad_sch, IO.kicad_sch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]
2023-03-22 hw: tidy IO, move CPU decoupling caps
    [CPU.kicad_sch, IO.kicad_sch, Mainboard.kicad_sch]
2023-03-23 hw: tidy audio, cass, IEEE, keyboard, magic, user
    [Audio.kicad_sch, CASS.kicad_sch, IEEE.kicad_sch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]
2023-03-23 hw: remove bar from video signal name
    [IEEE.kicad_sch, MAGIC.kicad_sch, Mainboard.kicad_sch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]
2023-03-23 hw: tidy cass more
    [CASS.kicad_sch]
2023-03-25 hw: comments
    [CASS.kicad_sch, IEEE.kicad_sch, IO.kicad_sch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]
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2023-03-26 hw: replace ram_ce with ram_a15
    [CPU.kicad_sch, FPGA.kicad_sch, MAGIC.kicad_sch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]
2023-03-27 hw: tidy MCU and a few missed PD_
    [IEEE.kicad_sch, MCU.kicad_sch, Mainboard.kicad_sch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]
2023-03-27 hw: move DVI to separate hierarchical sheet, fix buses, annotate power
    [Audio.kicad_sch, CASS.kicad_sch, CPU.kicad_sch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]
2023-03-27 hw: move microSD to it's own sheet
    [DVI.kicad_sch, MCU.kicad_sch, Mainboard.kicad_sch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]
2023-03-28 hw: move usb to it's own sheet
    [Audio.kicad_sch, DVI.kicad_sch, FPGA.kicad_sch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]
2023-03-28 hw: move flash to separate sheet
    [FLASH.kicad_sch, MCU.kicad_sch, Mainboard.kicad_sch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]
2023-03-28 hw: USB CC1/CC2 = 56k
    [Audio.kicad_sch, FLASH.kicad_sch, FPGA.kicad_sch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]
2023-03-29 hw: Use 74HC154 for keyboard
    [Audio.kicad_sch, FPGA.kicad_sch, Keyboard.kicad_sch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]
2023-05-05 wip: support 8x16 keyboard matrix
    [FPGA.kicad_sch, Keyboard.kicad_sch, MAGIC.kicad_sch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]
2023-05-06 wip: keyboard ex header
    [Audio.kicad_sch, Keyboard.kicad_sch, Mainboard.kicad_pcb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]
2023-05-13 hw: autoroute
    [Audio.kicad_sch, CASS.kicad_sch, FPGA.kicad_sch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]
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2023-05-18 hw: update 10u caps
    [CPU.kicad_sch, DVI.kicad_sch, FLASH.kicad_sch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]
2023-07-04 hw: routing / silk wip
    [DVI.kicad_sch, FPGA.kicad_sch, IEEE.kicad_sch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]
2023-07-04 hw: minor cleanup
    [FPGA.kicad_sch, Mainboard.kicad_pcb, Mainboard.kicad_sch]
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2023-07-15 hw: unstitched copper fills
    [Mainboard.kicad_sch, POWER.kicad_sch, USB.kicad_sch]
2023-07-16 hw: stitched copper planes (wip)
    [Audio.kicad_sch, FLASH.kicad_sch, FPGA.kicad_sch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]
2023-07-16 hw: heat sink, trace size, more stitching
    [Audio.kicad_sch, DVI.kicad_sch, FPGA.kicad_sch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]
2023-07-16 hw: Production for files JLCPCB
    [bom.csv, positions.csv]
2023-07-20 HW: Remove 'MANUFACTURER' and 'MAXIMUM_PACKAGE_HEIGHT' cols from BOM
    [FPGA.kicad_sch]
2023-07-20 HW: Rename 'MFR' to 'MPN' in BOM
    [POWER.kicad_sch]
2023-07-21 hw: add more Mouse part numbers
    [CASS.kicad_sch, CPU.kicad_sch, FLASH.kicad_sch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]
2023-07-21 hw: PN for IC, remove dup PNs, remove redundant headroom text on PWR
    [CPU.kicad_sch, FPGA.kicad_sch, IEEE.kicad_sch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]
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2023-07-24 hw: move GND via under user port pin 1
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2023-07-28 hw: thermal vias, whitespace, refill
    [Audio.kicad_sch, DVI.kicad_sch, FPGA.kicad_sch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]
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2023-11-16 fw: sd build fix
    [sd.c]
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
